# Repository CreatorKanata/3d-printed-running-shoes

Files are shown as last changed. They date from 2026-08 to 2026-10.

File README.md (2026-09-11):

<!-- README.md | Project overview and navigation | Introduce the K-Dash research project. -->

# K-Dash: Fully DIY 3D-Printed Running Shoes Designed for Speed

<p align="center">
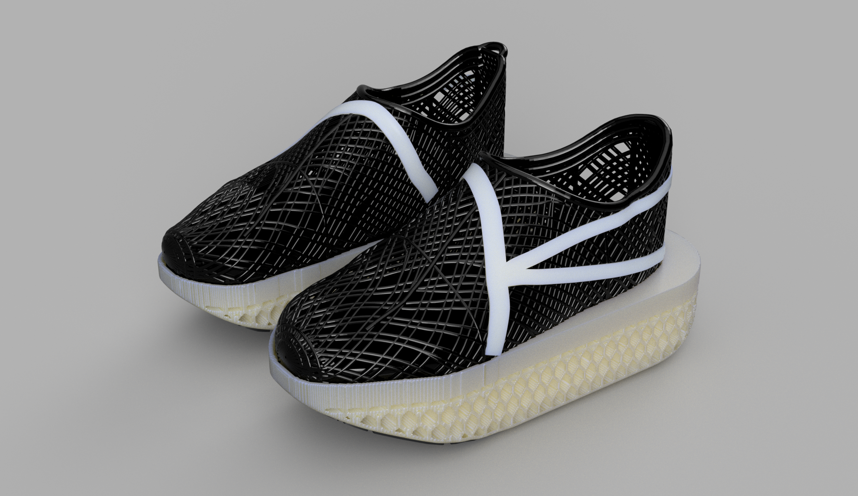
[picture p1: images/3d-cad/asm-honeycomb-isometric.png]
Isometric view of the fully DIY K-Dash 3D-printed running shoes
  
</p>

<p align="center">
  <a href="https://www.youtube.com/watch?v=hppxPRyWNDw">
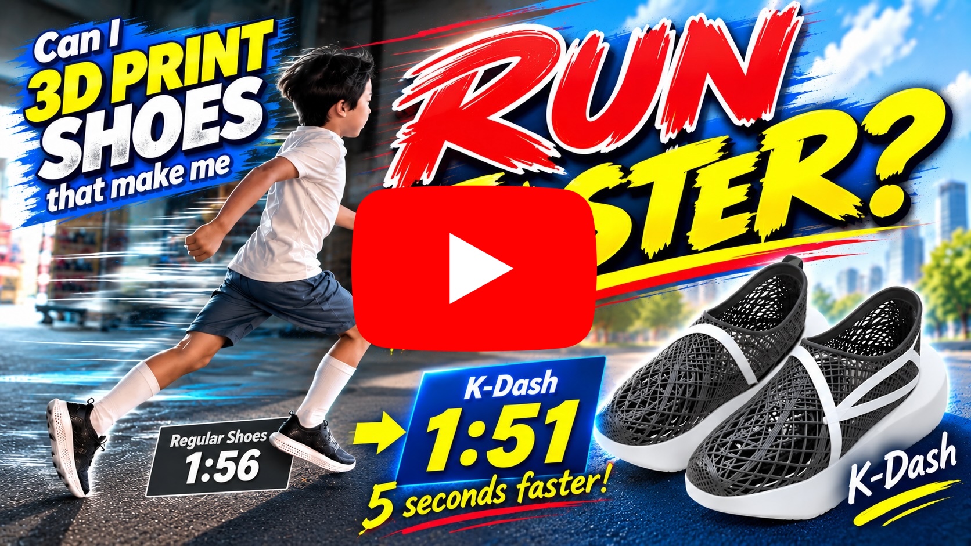
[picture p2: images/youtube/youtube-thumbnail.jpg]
Watch the K-Dash project video on YouTube
    
  </a>
</p>

This summer research project was conceived by Kanata, a third-grade elementary school student. By scanning his own feet and learning about shoe design from his running club coach, he is taking on the challenge of making K-Dash: fully DIY running shoes designed for speed, using AI, 3D CAD, and a 3D printer. His father offers technical suggestions and support with scanning, CAD, material selection, and printing.

## Research Goals

Explore the design features of shoes intended for faster running while making running shoes that fit his own feet.

- Investigate the raised toe, thick sole, and plate features described by the coach.
- Examine commercially available shoes for design ideas.
- Scan his feet in 3D and design closely fitting uppers.
- Find suitable 3D-printing settings through small prototypes and material comparisons.
- Incorporate a polycarbonate plate that can be made at home into the sole.

## Filament Used in the Final Version

- Filament: [Siraya Tech Flex TPU Air Active Foaming 3D Printer Filament](https://www.amazon.co.jp/dp/B0DZCD4Z9M)
- Colors: White and Black
- Nozzle diameter: 0.6 mm

## Research → Design → Build

### 1. Learn from the Coach and Examine Commercial Shoes

<p align="center">
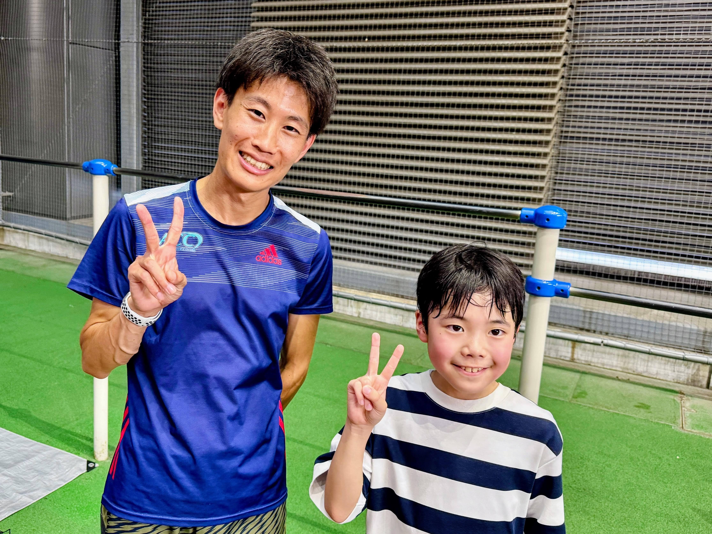
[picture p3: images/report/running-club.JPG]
Running club coach
  
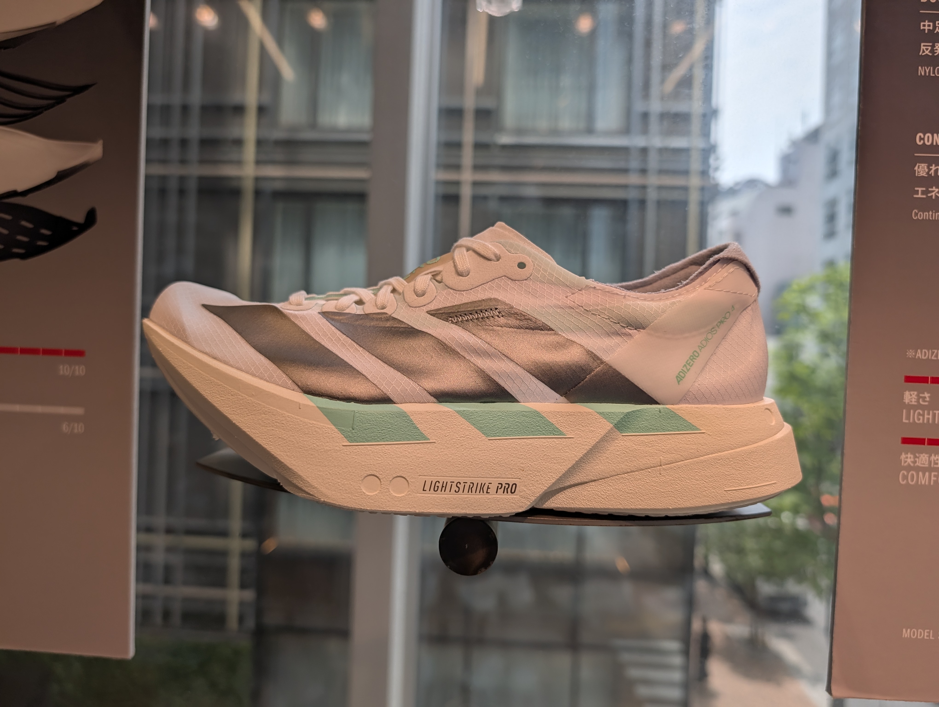
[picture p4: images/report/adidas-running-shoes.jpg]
Running shoes examined at an Adidas store
  
</p>

The coach explained that shoes designed for faster running feature raised toes, thick soles, and plates. We examined actual shoes at an Adidas store in Tokyo and used these features as references for our own shoes.

<p align="center">
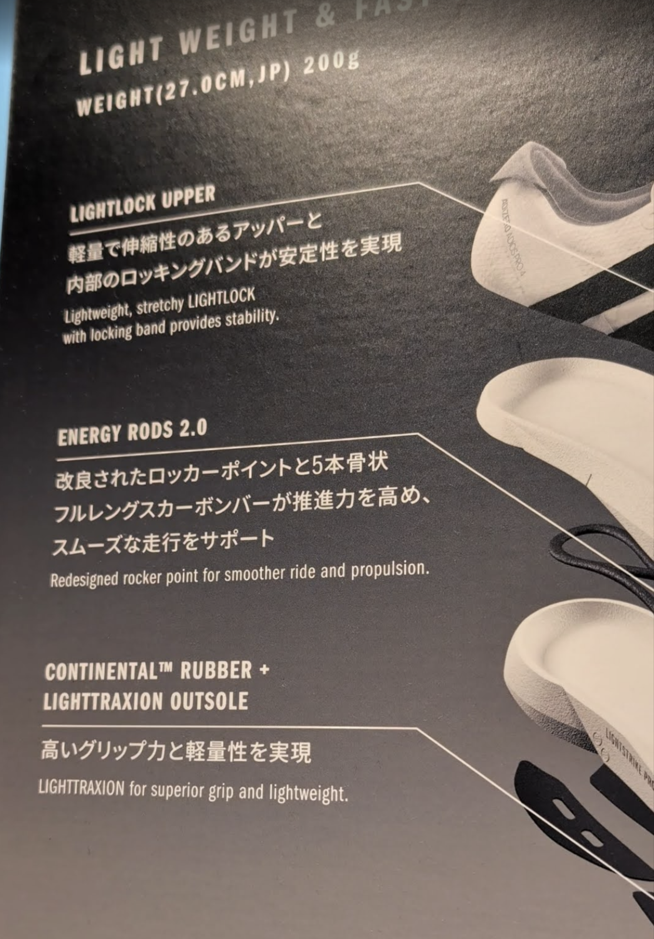
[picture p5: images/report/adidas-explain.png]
Explanation of running shoe construction at the Adidas store
  
</p>

### 2. Turn His Feet into 3D Data

<p align="center">
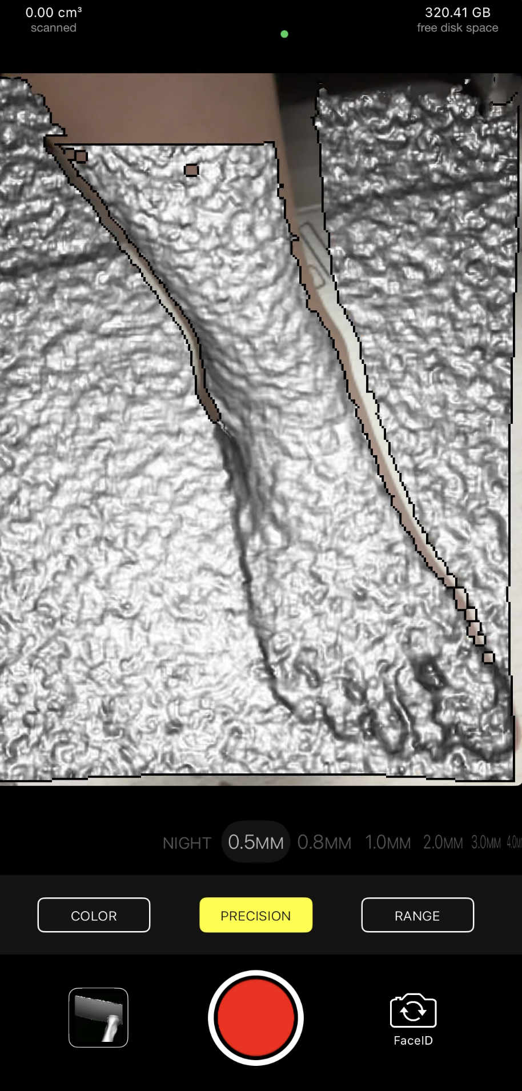
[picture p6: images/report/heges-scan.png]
Scanning a foot in 3D with Heges
  
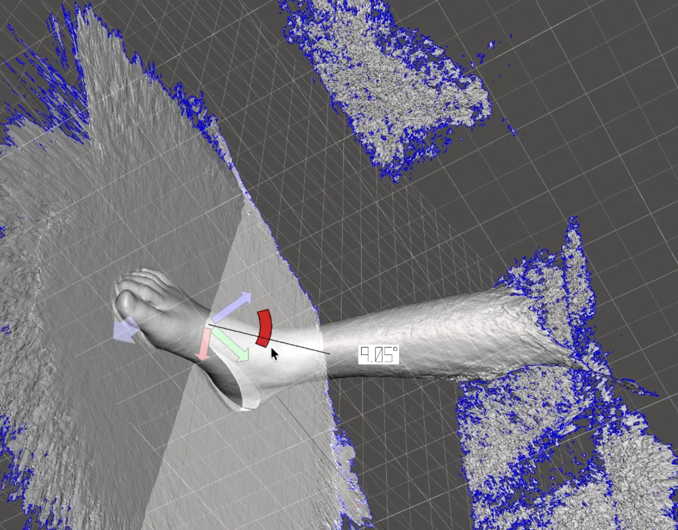
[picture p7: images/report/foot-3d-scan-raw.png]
Raw foot scan containing noise
  
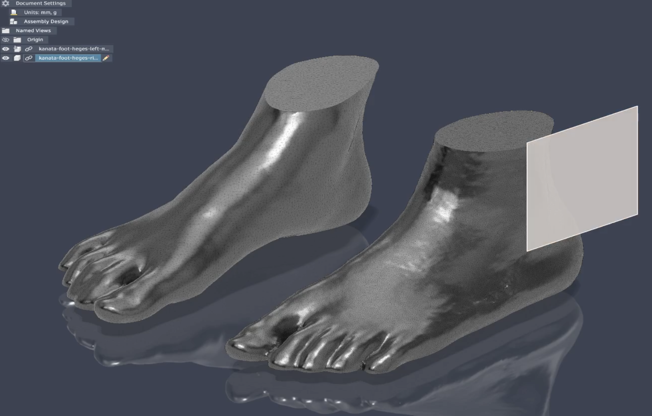
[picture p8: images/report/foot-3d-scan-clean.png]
Foot scan after removing noise
  
</p>

We scanned both feet with Heges and an iPhone's TrueDepth sensor at approximately 0.5 mm accuracy. After removing unwanted areas such as the floor, we prepared the foot models for designing the uppers.

### 3. Design with AI and 3D CAD

<p align="center">
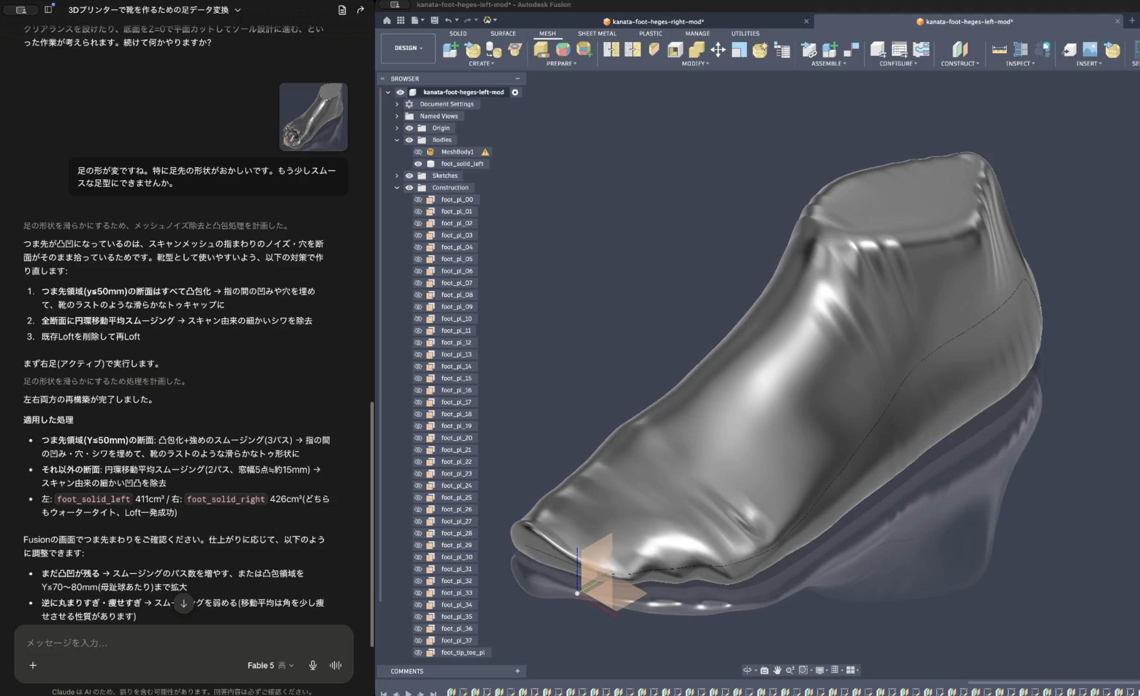
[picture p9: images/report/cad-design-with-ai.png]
Designing with AI and Autodesk Fusion
  
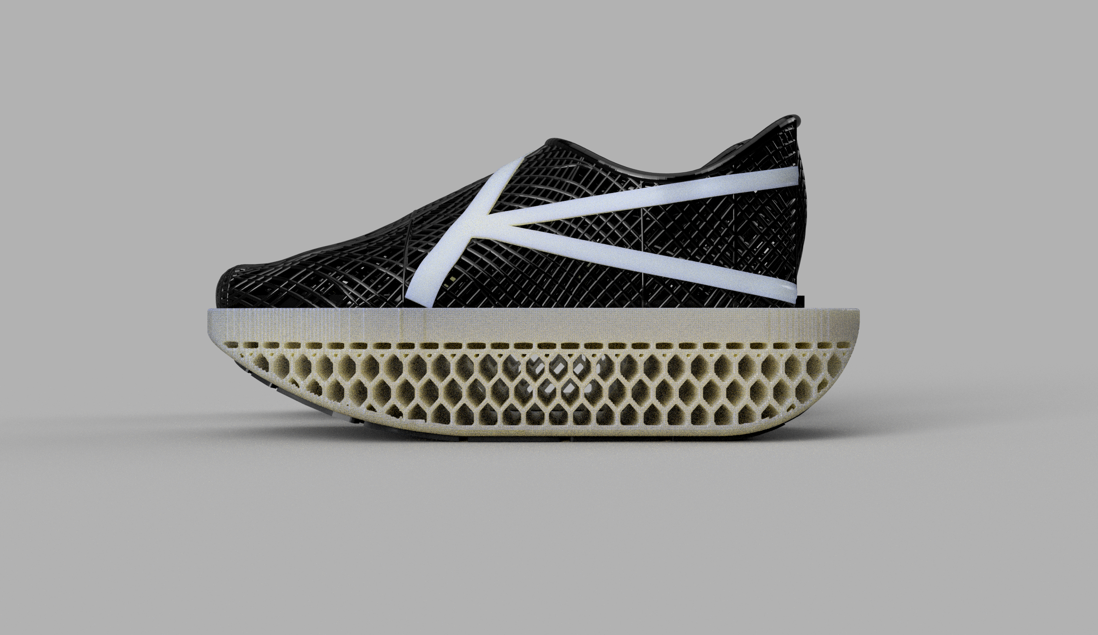
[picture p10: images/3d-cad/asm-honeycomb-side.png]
Side view of the shoe design with a honeycomb sole
  
</p>

We designed the shoes in Autodesk Fusion. By describing the desired shapes to AI and using its help to operate Fusion through MCP, we explored fitted uppers, a raised toe shape, and a honeycomb structure to reduce weight.

### 4. Iterate with 3D-Printed Prototypes

<p align="center">
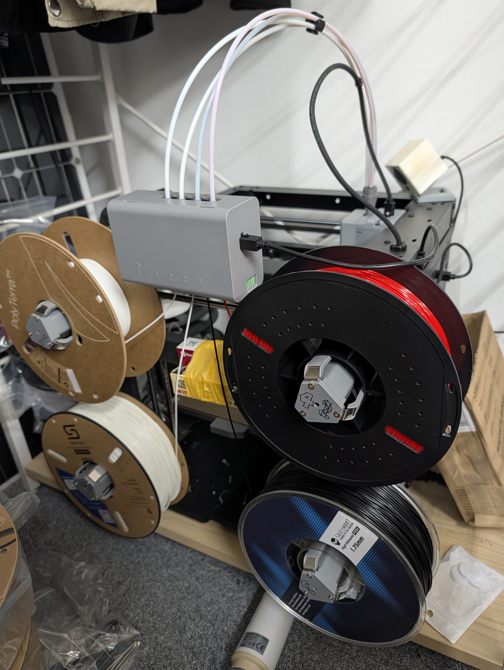
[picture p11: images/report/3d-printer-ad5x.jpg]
FlashForge AD5X 3D printer used for the project
  
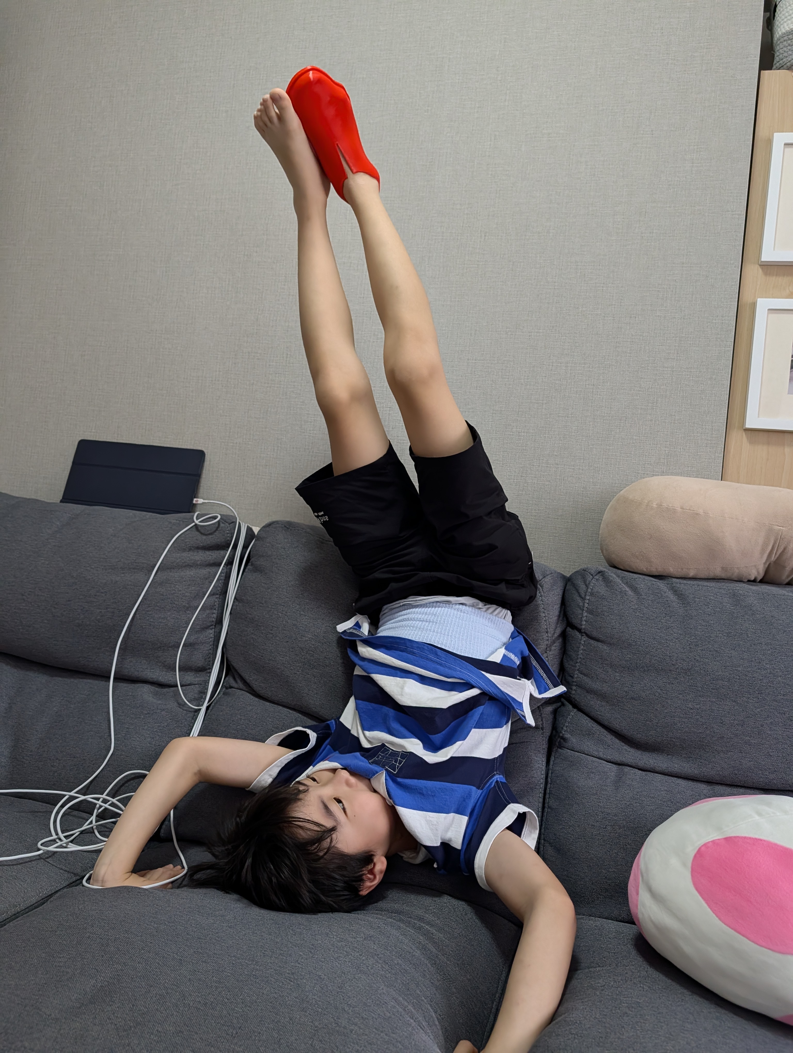
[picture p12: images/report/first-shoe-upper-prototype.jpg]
Trying on the first upper prototype to check the fit
  
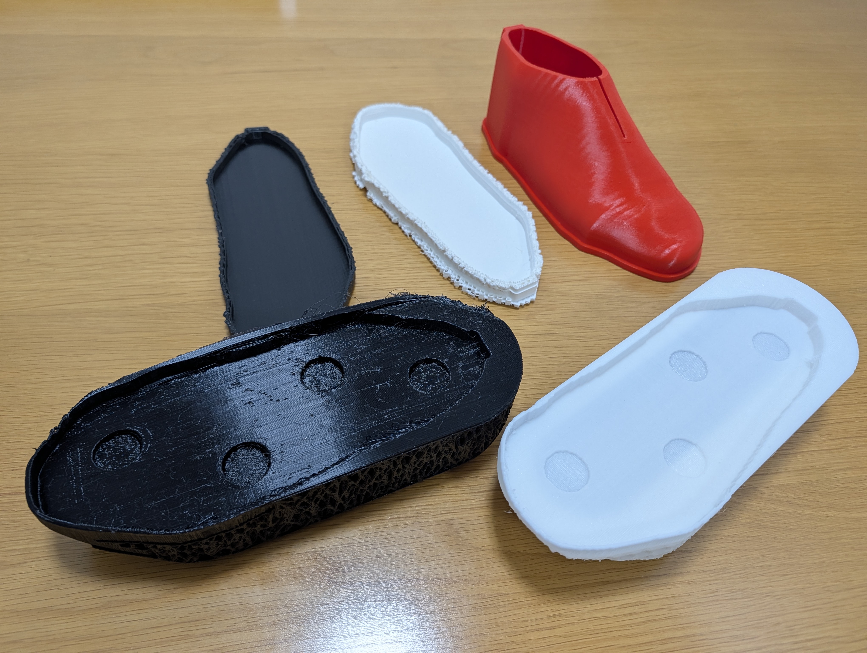
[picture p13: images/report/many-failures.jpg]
Prototypes and failed TPU prints
  
</p>

We first printed only the uppers on a FlashForge AD5X to check the fit. For the final version, we used White and Black Siraya Tech Flex TPU Air with a 0.6 mm nozzle. Soft TPU was challenging to print, so we made many prototypes while adjusting the temperature, nozzle diameter, and filament feeding method.

### 5. Insert a Polycarbonate Plate into the Sole

<p align="center">
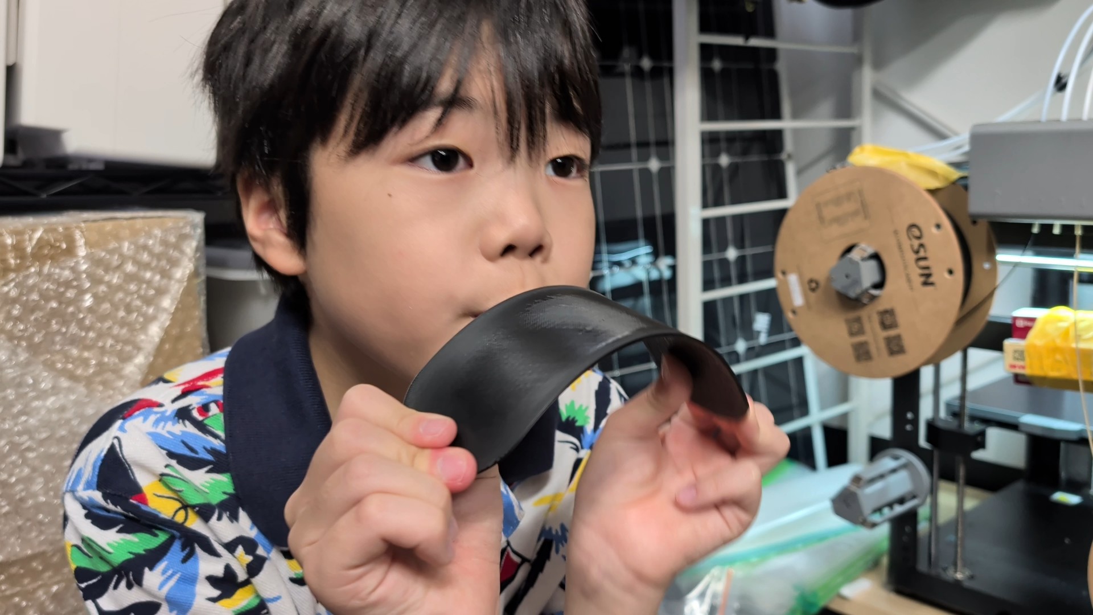
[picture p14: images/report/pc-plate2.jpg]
Polycarbonate plate that springs back after bending without breaking
  
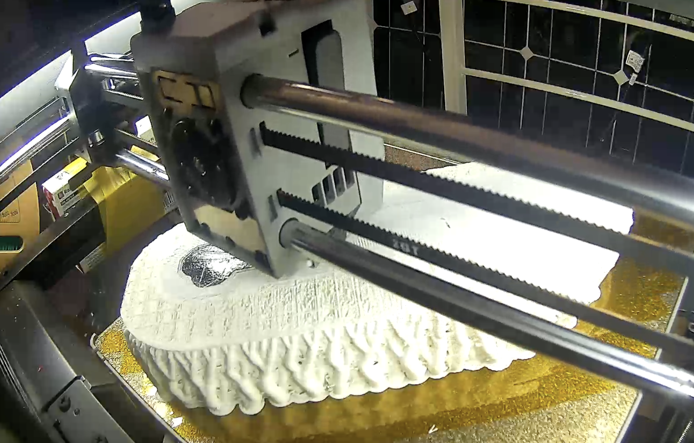
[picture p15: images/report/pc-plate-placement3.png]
Print with a polycarbonate plate embedded in the sole
  
</p>

Because carbon plates are difficult to fabricate at home, we used polycarbonate plates that could be made with a 3D printer. We paused the sole print, placed the plate inside, and resumed printing to embed it in the TPU.

## Folder Structure

| Location | Contents |
| --- | --- |
| [`docs/report/`](docs/report/) | Research report, A3 sketchbook layouts, and sample comments for parents. |
| [`docs/sole-ai/`](docs/sole-ai/) | Technical notes on AI-assisted sole design, lattice structures, and 3D printing. |
| [`images/report/`](images/report/) | Research photos, screenshots, and their descriptions. |
| [`images/3d-cad/`](images/3d-cad/) | Shoe design renderings created with AI and 3D CAD. |
| [`3d-models/`](3d-models/) | Uppers, soles, plates, and slicer profiles for 3D printing. |
| [`sole-ai/`](sole-ai/) | Python tools and tests for generating left and right sole design candidates. |

## Read the Research Report

Descriptions of the research images are collected in [images/report/README.md](images/report/README.md). For the ten-page A3 portrait sketchbook layout, see [docs/report/a3-sketchbook-layout/README.md](docs/report/a3-sketchbook-layout/README.md).

## Sole Design Tools

`sole-ai` is a tool for exploring left and right sole shapes, plate placement, and internal lattice structures. See [sole-ai/README.md](sole-ai/README.md) for usage and design assumptions.

Intermediate candidate data is stored in `sole-ai/outputs/`, and generated files such as PDFs are stored in `output/`. These are not tracked in Git.

## Safety

The 3D models in this repository are intended for research and prototyping. Before running in the shoes, thoroughly check component strength, bonding, and fit. Decide whether to use them for long-distance running or competition only after verifying their safety.

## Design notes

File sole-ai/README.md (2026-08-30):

# Sole AI

`sole-ai` is the starting point for designing left and right 3D-printed racing-shoe soles from scanned geometry, runner intent, and measured test results.

It deliberately separates two jobs:

1. Fusion owns the editable B-Rep master model: sole envelope, upper interface, plate pocket, rocker, and assembly.
2. This project preserves the supplied thick outsole/midsole envelope and creates bounded internal design candidates: a continuous TPU-density field, a curved upper/bottom-midsole split surface, and PC-plate placement. The selected baseline derives the plate outline from the actual left or right sole, leaves the rear cushioning zone plate-free, and follows a moderated version of the outsole rocker. Those candidates are later evaluated by FEA and running tests.

The current manufacturing direction is an FFF-oriented, gently warped, functionally graded walled Gyroid. The earlier stochastic beam network is retained only as rejected research: once constrained for FFF it looked like vertical curtains, and when made visually denser it did not produce a reliable manufacturing mesh. Fusion remains the reference for the locked envelope, curved split, and plate. The density field is a documented load-path heuristic until runner pressure, coupon tests, and FEA data are available, so it does **not** yet predict running performance.

## Geometry to supply

Keep the original Fusion archive (`.f3d`) if it exists. For every side, export the following into `data/raw/<side>/`:

| Priority | Format | Purpose |
| --- | --- | --- |
| Required master | `sole-envelope.step` (AP242, millimetres) | Fusion-editable B-Rep source for all later CAD operations. |
| Required mesh companion | `sole-envelope.stl` (binary, millimetres, watertight) | Mesh validation and implicit growth-lattice generation. |
| Optional | `sole-envelope.3mf` | Preserves slicer/material/print metadata; it is not the CAD master. |
| Strongly recommended | `upper-reference.step` and/or `upper-reference.stl` | Locks the sole to the existing custom upper coordinate frame. |

Export a **closed solid** that includes the entire intended sole envelope—not a 2D outline, an open top surface, or a sliced print plate. The initial Fusion exports use this valid source convention:

```text
X: transverse / width
Y: toe (-) to heel (+)
Z: ground/bottom (-) to upper (+)
units: millimetres
```

The validator infers these axes from the mesh dimensions and records them in each candidate manifest; it never rotates the source CAD. In the Fusion side view used for review, negative Y is screen-right, so the raised plate end is the visible toe. If the upper and sole were exported from different coordinate systems, also place `landmarks.json` next to each side. It must contain at least `heel_center`, `first_met_head`, `fifth_met_head`, and `toe_center` in millimetres. The project will use this later to register the two parts safely.

Do not rely on STL alone for editable Fusion work: STL contains triangles, normally lacks unit metadata, and loses feature history. STEP plus the original `.f3d` is the correct source-of-truth combination. A high-resolution binary STL remains useful for implicit-field work.

## Quick start

This project uses only the Python standard library. Python 3.11 or later is required.
Before physics scoring, replace the `null` runner fields in `configs/baseline.json` with measured values.

```bash
cd sole-ai
python3 -m sole_ai.cli validate --side left
python3 -m sole_ai.cli generate --side left --count 12 --seed 42
python3 -m sole_ai.cli generate-variable-lattice --side left
python3 -m sole_ai.cli generate-organic-lattice --side left
python3 -m sole_ai.cli generate-envelope-lattice --side left
python3 -m unittest discover -s tests -v
```

Copy the generated `outputs/<side>/candidate-*.json` values into the named parameters of the Fusion master model. They are design intents, not a manufacturing model. Do not print a candidate until it has passed the future geometry, FEA, and physical-test gates.

`generate-variable-lattice` writes closed upper/lower STLs and a constraint manifest under `outputs/<side>/lattice/cellular-foam-v2/`. It also writes `*-flashstudio.stl` copies rotated diagonally and moved to Z=0 inside the AD5X 220×220 mm plate. Add `--preview` for Fusion visual-review meshes. Both the manufacturing pair and current high-detail preview use a 1 mm scalar grid.

To create the first actual B-Rep bodies, run the Fusion script in [fusion_addin/README.md](fusion_addin/README.md) after opening the matching STEP. It exports separate Upper Midsole, Bottom Midsole, and PC Plate STEP/3MF files.

When Fusion is unavailable, this project can still create watertight baseline STL bodies that preserve the supplied thick outer shape. This output has no PC-plate pocket or lattice, so use it for visual, fit, and split-line review—not for a final assembled shoe.

```bash
python3 -m sole_ai.cli generate-mesh \
  --candidate outputs/left/candidate-left-0042-001.json
```

## FFF TPU lattice core

The manufacturing-process review and acceptance criteria are recorded in
[../docs/sole-ai/FFF_TPU_LATTICE_RESEARCH.md](../docs/sole-ai/FFF_TPU_LATTICE_RESEARCH.md). The blue
Nagase reference is a photopolymer aesthetic target; AD5X output must additionally
satisfy FFF build-direction, overhang, and bridge constraints.

The selected AD5X topology is a continuous Gyroid surface with gentle long-wave phase warping. Pressure and FEA data will vary exact wall thickness smoothly, while a minimum wall is preserved everywhere. This sacrifices exact visual reproduction of the blue Nagase photopolymer reference in exchange for the FFF TPU printability and fatigue evidence documented in the research note.

An explicitly requested organic alternative is also available through
`generate-organic-lattice`. It grows irregular curved branches independently
inside each scanned left/right envelope, blends their junctions as one implicit
field, and rejects any non-watertight output. Its requested minimum branch
diameter is 1.2 mm; current branch shafts are designed between 1.6 and 1.8 mm.
The dense V2 uses a 5.0 mm nominal cell scale, 4.0--6.0 mm graded node spacing,
and three or four parent branches per node. Only the multi-branch nodes become
locally wider as the branches merge. It remains a test candidate until coupon
and cyclic-compression validation are complete.

When the designer supplies `sole-lattice-left/right.step` plus matching closed
STLs, `generate-envelope-lattice` fills each dedicated volume directly. It does
not split the volume at a plate plane. Every disjoint vertical solid interval is
sampled separately, so a designed gap between stacked or stepped source parts
remains empty. V10 uses independently sampled attraction points in every build
layer. An orthotropic k-nearest graph grows toward them, then adds anastomosis
links so branches split and merge instead of forming a regular vertical grid.
Curved branches are fused by a smooth implicit union. This research basis and
the implementation choices are recorded in
[`../docs/sole-ai/BIOLOGICAL_LATTICE_RESEARCH.md`](../docs/sole-ai/BIOLOGICAL_LATTICE_RESEARCH.md).

The 1.2 mm conformal top/bottom anchors eliminate free branch tips at the two
assembly interfaces. No side anchor or side shell is added. Every complete
branch cross-section stays inward from the lateral boundary, so a free branch
cannot terminate by being clipped on a left/right side face. Free branch shafts
vary continuously across the requested 1.5--2.0 mm range. The V10 branch/node
plan-view density target is 50% of V8: node targets are multiplied by 0.50,
while spacings and coverage radii are multiplied by `1/sqrt(0.50)`. This changes
network count density rather than promising a proportional material reduction.
Intervals 6 mm thick or thinner remain solid to preserve their designed edge
shape. The production-grid single-parent-node ratio is 8.15% left and 8.83%
right, so V10 caps it at 9% while retaining the average-link,
no-dead-end, side-clearance, and 45-degree build-angle gates.

- Forefoot propulsion zone: thickest TPMS walls near toe-off.
- Plate load path: locally reinforced around the approved low rocker-following PC plate.
- Midfoot and heel rim: moderate wall reinforcement.
- Central heel and lightly loaded transitions: thinner walls without disconnected gaps.

The requested minimum feature is 1.5 mm. The first 0.6 mm-nozzle coupon range is deliberately more conservative: 2.4--3.2 mm TPMS wall thickness. A 3 mm ground skin, 2 mm upper bonding skin, and 2 mm solid TPU support on both faces and around the edge of the PC-plate pocket remain mandatory. No full-sole STL is currently labelled print-ready; see the research note for the failed gates and coupon plan.

## Thick-sole constraint

The supplied shoes use a thick, smooth rocker midsole. In V1, `sole-envelope.step` remains the external boundary: the AI must not reduce stack height or change the approved rocker. It may open the side volume to reveal the growth lattice while preserving solid top, ground, and plate interfaces. The plate is centred on a curved split surface derived from the measured outsole underside, so both printed TPU parts capture it.

## Project layout

```text
data/raw/                 input CAD and mesh files, never generated files
configs/                  runner and manufacturing constraints
outputs/                  reproducible candidate manifests
../docs/sole-ai/          research and manufacturing notes
sole_ai/                  standard-library Python package
tests/                    regression tests
```

## Development sequence

1. Add left and right STEP/STL envelope pairs and validate their bounds.
2. Build the Fusion master model by retaining the supplied outer envelope and using the internal named parameters emitted by this project.
3. Replace the design-manifest export with a geometry adapter for the Fusion API.
4. Calibrate the cell-spacing-and-diameter-to-stiffness relation with printed coupons.
5. Add quasi-static FEA and plantar-pressure data, then replace the current smooth heuristic field with optimized runner-specific weights.

This order keeps the first prototypes inspectable and avoids training an "AI" on unverified assumptions.

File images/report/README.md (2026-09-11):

<!-- images/report/README.md | Research image captions | Explain the process and findings alongside the photos. -->

# Image Descriptions for the Research Project

These descriptions accompany the photos and screenshots in this folder for the research project, “Making 3D-Printed Running Shoes That Fit My Feet.” To explain the process and design choices clearly, arrange the report in this order: **motivation → commercial shoe research → foot scanning and design → reviewing the finished CAD design → printing and prototyping → soles with embedded plates → finished shoe weight and running tests**.

Each “Suggested caption” is intended to fit beside or below its image. Commercial shoe specifications vary by model, so describe what can be seen in the photos.

## 1. Motivation and Commercial Shoe Research

### `running-club.JPG` — Learning About Fast Shoe Designs from the Coach

**Suggested caption:** My running club coach taught me that running shoes have features designed to help people run faster. I used carbon plates, raised toes, and thick soles as ideas for my own shoes.

**Key point:** Before making my shoes, I asked an expert how shoes can make running easier.

### `adidas-store.png` — Examining Shoes at an Adidas Store

**Suggested caption:** I visited an Adidas store in Tokyo to learn about the running shoes my coach recommended. Seeing them in person helped me observe shapes and materials that photos alone could not show.

**Key point:** I gathered design ideas by examining actual commercial shoes.

### `adidas-explain.png` — An In-Store Explanation of Shoe Construction

**Suggested caption:** The store had a display explaining how running shoes are built. I learned that shoes are more than their appearance: soles, plates, and other parts help make running easier.

**Key point:** The store display helped me learn how shoes work inside.

### `adidas-running-shoes.jpg` — Features of Modern Running Shoes

**Suggested caption:** The running shoes in the store had features my coach described, including raised toes, thick soles, and structures containing carbon components.

**Key point:** I could see the features my coach described in actual shoes.

### `competitive-analysis.jpg` — Comparing Shoe Brands

**Suggested caption:** With help from AI, I researched the features of different running shoe brands. I learned that companies use plates and cushioning in different ways.

**Key point:** I compared ideas from several companies to inform my design.

### `competitor-adidas.png` — Competitor Research: adidas

**Suggested caption:** I studied adidas shoe structures containing carbon components. I learned that springy parts are used to help move the foot forward.

**Key point:** I used carbon-based spring-back features as a design reference.

### `competitor-new-balance.png` — Competitor Research: New Balance

**Suggested caption:** I studied an example of New Balance shoes with a wavy carbon plate. I learned that companies also have different ideas about plate shapes.

**Key point:** Even carbon plates can use different shapes to achieve their design goals.

### `competitor-nike.png` — Competitor Research: Nike

**Suggested caption:** I studied Nike shoes that combined carbon components with air cushioning near the front. I learned that plates and cushioning can be used together.

**Key point:** I considered cushioning, as well as spring-back, important for comfortable running.

## 2. Turning My Feet into 3D Data

### `heges-scan.png` — Scanning My Feet with Heges

**Suggested caption:** To make uppers that fit well, I scanned both feet with an app called Heges. Using the iPhone's TrueDepth sensor, I captured their shapes at approximately 0.5 mm accuracy.

**Key point:** I first measured my foot shapes accurately to make shoes fitted to my feet.

### `foot-3d-scan-raw.png` — The Raw Foot Scan

**Suggested caption:** The scan captured the floor and nearby objects as well as my feet. I needed to remove the unwanted parts before using the data to design the shoes.

**Key point:** The raw 3D scan needed cleaning before it could be used.

### `foot-3d-scan-clean.png` — The Foot Scan After Removing Noise

**Suggested caption:** After cutting away the floor and surrounding noise, only the 3D foot data remained. I used it to design uppers matching my feet.

**Key point:** Cleaning the data produced foot models suitable for design.

## 3. Designing with AI and 3D CAD

### `cad-design-with-ai.png` — Designing with AI and Autodesk Fusion

**Suggested caption:** I used Autodesk Fusion, a 3D CAD application, for the design. I described the shapes I wanted to AI tools such as Claude and GPT-5.6 Sol, which helped operate Fusion through MCP.

**Key point:** I used AI as a tool to turn my ideas into 3D shapes.

### `../3d-cad/asm-honeycomb-front.png` — Front View of the Finished Design

**Suggested caption:** This is a front view of the shoes designed with AI and CAD. I checked the combination of mesh-like uppers and soles that support the feet.

**Key point:** 3D CAD lets me check the overall balance of the shoes from different directions before printing.

### `../3d-cad/asm-honeycomb-side.png` — Side View of the Finished Design

**Suggested caption:** The side view shows the thick honeycomb soles and raised toes. I chose a honeycomb structure instead of solid soles to try to reduce weight.

**Key point:** I used CAD to explore shapes for easier running and structures for lower weight.

### `../3d-cad/asm-honeycomb-isometric.png` — Isometric View of the Finished Design

**Suggested caption:** This angled view shows how the mesh-like uppers, white foot-support reinforcements, and honeycomb soles fit together. I told AI what I wanted to make and checked the overall design in CAD.

**Key point:** 3D CAD lets me adjust the design while checking how the parts connect.

## 4. Prototyping and Adjusting the 3D Prints

### `3d-print-slicer.jpg` — Preparing Prints with a Slicer

**Suggested caption:** I used software called a slicer to convert the CAD models into data the 3D printer could use. I checked the layers and printing order before printing.

**Key point:** A CAD model needs preparation before a 3D printer can print it.

### `3d-printer-ad5x.jpg` — The 3D Printer Used

**Suggested caption:** I made the running shoe parts with a FlashForge AD5X 3D printer. Using a printer suitable for home use allowed me to make repeated prototypes.

**Key point:** A 3D printer can turn my design ideas into physical parts.

### `many-failures.jpg` — Adjusting Print Settings Through Many Failures

**Suggested caption:** I made many prototypes, but soft TPU was especially difficult to print. Printing finally became stable after adjusting the temperature, changing the nozzle from 0.4 mm to 0.6 mm, and using a setup without the filament switcher.

**Key point:** I learned to record failures, consider their causes, and change conditions one at a time.

### `first-shoe-upper-printing.jpg` — Printing the First Upper

**Suggested caption:** I first printed only the upper, the top part of the shoe, to check the fit. I tested a smaller part before making the whole shoe.

**Key point:** I started by making and testing one part to reduce failures.

### `first-shoe-upper-prototype.jpg` — Trying On the First Upper

**Suggested caption:** When I tried on the first upper, it fitted my foot well. Using the scanned foot data helped me make a shape suited to my foot.

**Key point:** The upper designed from the scan also fitted well when worn.

### `shoe-upper-printing.png` — Printing the Full Upper Design

**Suggested caption:** I also printed the full upper design. After trying TPU, PEBA, and other materials and repeatedly adjusting failed prints, I found that White and Black Siraya Tech Flex TPU Air, an active foaming filament, worked best with a 0.6 mm nozzle. For this print, I used a nozzle temperature of 260°C for a hardness of 70A.

**Key point:** Materials differ in hardness and comfort, so I compared them to choose the best fit for the project.

### `insert-insole.png` — Adding an Insole

**Suggested caption:** I added insoles to make the shoes more comfortable. I combined the printed uppers with insoles and adjusted them to reduce rubbing against my feet.

**Key point:** I improved comfort with insoles as well as printed parts.

### `shoe-upper-finish.png` — The Finished Upper with an Insole

**Suggested caption:** The uppers still fitted well after adding the insoles. I confirmed that the custom uppers and insoles worked well together.

**Key point:** I kept checking the fit by trying on the shoes through the final stage.

## 5. Embedding Polycarbonate Plates in the Soles

### `pc-plate1.jpg` — Making a Plate Instead of Using Carbon

**Suggested caption:** Carbon plates were difficult to fabricate at home, so I 3D-printed polycarbonate plates instead. This let me make them inexpensively at home without laser cutting.

**Key point:** I adapted the design by choosing a material I could work with at home.

### `pc-plate2.jpg` — Testing Plate Strength and Spring-Back

**Suggested caption:** When I bent the polycarbonate plate, it strongly tried to return to its original shape without breaking. I tested it by bending it to see whether it could substitute for a carbon plate.

**Key point:** I physically bent the part to test its strength and spring-back.

### `pc-plate-placement1.png` — Choosing Where to Pause the Print

**Suggested caption:** To insert the plate during printing, I paused the sole print when it reached the height where the plate would sit.

**Key point:** I planned an extra step during printing to combine different materials.

### `pc-plate-placement2.png` — Placing the Plate

**Suggested caption:** After pausing the print, I placed the polycarbonate plate, already coated with adhesive, inside the sole.

**Key point:** I considered placement and bonding to keep the plate from shifting.

### `pc-plate-placement3.png` — Resuming the Print to Embed the Plate

**Suggested caption:** Resuming the print after placing the plate embedded it inside the TPU sole. The sequence “pause → place the plate → resume” combined different materials into one sole.

**Key point:** A home 3D printer could produce a sole combining different materials.

## 6. Assembling K-Dash and Testing Weight and Running

### `glue-shoes.png` — Bonding the Uppers and Soles

**Suggested caption:** I glued the printed uppers and soles together to assemble a pair of K-Dash shoes. Aligning the separately made parts was another important step in making the shoes.

**Key point:** I combined the designed and printed parts into wearable shoes.

### `k-dash-wearing.jpg` — Wearing the Finished K-Dash on Both Feet

**Suggested caption:** I tried the finished K-Dash on both feet. These custom running shoes combine black uppers made from scans of my feet with white 3D-printed soles.

**Key point:** The parts I designed, printed, and assembled became shoes I could wear on both feet.

### `weight-normal.jpg` — Regular Shoe Weight: 204 g

**Suggested caption:** For comparison, I weighed the regular running shoes and recorded 204 g. I used this as a baseline for considering how heavy or light K-Dash was.

**Key point:** Measuring weight in the same way lets me compare my shoes with commercial shoes.

### `weight-v1.jpg` — K-Dash v1 Weight: 411 g

**Suggested caption:** K-Dash v1, made with PEBA and TPU, weighed 411 g. Since it was heavier than the regular shoes, I aimed to make the next version lighter.

**Key point:** Measuring the weight showed in numbers what needed improvement.

### `weight-v2.jpg` — K-Dash v2 Weight: 268 g

**Suggested caption:** K-Dash v2, made with TPU Air, weighed 268 g. That was 143 g, or about 35%, lighter than v1 at 411 g. It was still heavier than the regular shoes at 204 g, but changing materials greatly reduced the weight.

**Key point:** I learned that changes to materials and design can substantially improve shoe weight.

### `running-test-normal.png` — Timing a 400 m Run in Regular Shoes

**Suggested caption:** I ran 400 m in regular shoes and timed the run to compare it with K-Dash. This became the baseline for running the same distance.

**Key point:** A comparison experiment needs a recorded baseline.

### `running-test0.png` — Checking K-Dash Before Running

**Suggested caption:** I put on K-Dash and checked the fit and sole condition before running. This finished version combined uppers fitted to my feet with lighter soles.

**Key point:** Before running, I checked whether the shoes fitted and appeared safe to use.

### `running-test2.png` — Running in K-Dash

**Suggested caption:** I ran in the finished K-Dash shoes. I checked that the printed uppers and honeycomb soles could function while running.

**Key point:** I went beyond making the shoes and tested them by wearing them and running.

### `running-side-view1.png` — Slow Motion: Sole Movement 1

**Suggested caption:** I filmed my feet from the side in slow motion while running. I observed the shape of the honeycomb soles during the run.

**Key point:** Slow-motion video lets me examine sole movement in detail.

### `running-side-view2.png` — Slow Motion: Sole Movement 2

**Suggested caption:** In another frame of the slow-motion video, I observed K-Dash from the side as my weight pressed on my foot. I used it to check changes in sole height and shape.

**Key point:** I observed how the soles changed at different stages of the running movement.

### `running-side-view3.png` — Slow Motion: Sole Movement 3

**Suggested caption:** In another frame, I observed my foot pushing off the ground. I checked whether the honeycomb sole kept its shape without breaking during the running movement.

**Key point:** Video helps inspect how parts move and whether they remain intact during running.

## Usage Notes

- Start with the “Suggested caption” below each image for readability.
- For scanning, prototyping, and plate tests, use the sequence **initial challenge → design choice or adjustment → finding** to explain the research process.
- Finish by comparing the regular shoes and K-Dash under the same conditions: 400 m times, comfort, and sole condition after running. This makes the results easier to understand.

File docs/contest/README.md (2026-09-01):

<!-- docs/contest/README.md | 科学コンテスト用A3縦2枚の使い方 | 要項に沿って印刷・提出するため -->

# 科学コンテスト 2026 提出用レイアウト

東京銀座ライオンズクラブ・早稲田大学科学コンテスト 2026の要項に合わせた、A3縦2枚のSVGです。

| ページ | 内容 |
| --- | --- |
| `k-dash-science-contest-page-1.svg` | 研究の動機、予想、調査、足の3Dスキャン、設計、試作と材料選び。 |
| `k-dash-science-contest-page-2.svg` | 重さと400m走の比較、走行中の観察、考察、次に調べること。 |

## 提出前の確認

- A3縦（297 mm × 420 mm）で、原寸・カラー印刷する。
- 先頭に研究テーマ、学校名、学年、氏名を記載済み。要項どおりクラス名は入れていない。
- 時間の結果は、400mをそれぞれ1回測った今回の比較である。靴だけの効果とは断定せず、次回は同じコース・条件で複数回測る計画を示している。
- 使用写真はSVGに埋め込んであるため、SVGファイルだけを別のパソコンに渡しても表示される。印刷前に、SVGをブラウザまたはInkscapeで開いて、画像が表示されることを確認する。
- 写真は自分たちで撮影したものとして使用する。外部の写真や図を追加する場合は、出典を追記する。

## 制作のねらい

色鉛筆・マーカー・手書き風の矢印や星を使いながら、見出しと測定値は太く読みやすくしました。独創性は「自分の足の3Dスキャンから靴を作ったこと」、分析力は「重さと400mの測定値、1回の測定だけでは結論にできないという考察」で伝える構成です。

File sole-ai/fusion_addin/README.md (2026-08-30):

# Fusion baseline-geometry generator

`sole_ai_fusion.py` is a Fusion script, not a command-line program. It creates real editable B-Rep components from a selected `sole-envelope.step` body and one Sole AI candidate JSON.

## What it generates

- `BOTTOM_MIDSOLE`: the supplied thick sole envelope below the candidate split surface.
- `UPPER_MIDSOLE`: the same envelope above that split surface.
- `PC_PLATE`: a clearance-pocketed PC plate whose planform is trimmed by a scaled copy of the actual left or right sole. It starts after the heel cushion, has a smooth semicircular rear cap, and follows a moderated version of the measured outsole rocker toward the negative-Y toe.
- `*.step`, `*.3mf`, and `sole-ai-assembly.f3d` under `outputs/<side>/geometry/<candidate-id>/`.

The source sole envelope is copied before it is split; it is hidden after a successful run but not deleted. The visible white exterior stays exactly as supplied. The generator creates an internal clearance pocket in both TPU components for the PC plate.

## Lattice responsibility

Fusion owns the reference CAD: locked sole envelope, approved rocker-following plate, and curved upper/lower split. The 2 mm upper skin, 3 mm ground skin, 2 mm plate supports, and biological open-cell lattice are fused into closed meshes outside Fusion by `python3 -m sole_ai.cli generate-variable-lattice --side <side>`.

Import the `lower/upper-organic-strut-preview.stl` pair only for visual review in Fusion. Use the matching non-preview pair as the high-resolution manufacturing source after slicer and coupon validation. Both pairs come from the same deterministic growth history; only surface sampling resolution differs.

Run `import_variable_lattice_preview.py` from **Utilities → Scripts and Add-Ins** to load that generated pair into the current Fusion design. The importer performs no lattice Boolean or density calculation in Fusion.

## Run it in Fusion

1. Open `data/raw/left/sole-envelope.step` or the matching right-side STEP in Fusion's **Design** workspace.
2. Open **Utilities → Scripts and Add-Ins**, add/run `sole_ai_fusion.py` from this folder.
3. Paste the absolute path to the matching candidate JSON when prompted, for example:

   ```text
   /Users/hide/src/github.com/CreatorKanata/3d-printed-running-shoes/sole-ai/outputs/left/candidate-left-0042-001.json
   ```

4. Select the imported closed sole B-Rep body.
5. Inspect the generated `SOLE_AI_<candidate-id>` component: ensure that the plate pocket remains inside the thick sole and that the outer silhouette has not changed.
6. Use the generated STEP files for edits and the 3MF files only after reviewing the clearance and print orientation.

## Fusion MCP execution

Fusion MCP can run the same workflow without modifying the source model that is already open. Import the matching STEP into a new, unsaved document, generate the assembly there, and export the result. This keeps the original scan-lock document untouched.

The low, rocker-following, heel-relieved pair has been generated from candidate `0042-001`:

| Side | Candidate | Generated directory |
| --- | --- | --- |
| Left | `left-0042-001` | `outputs/left/geometry/left-0042-001-low-rocker-smooth-heel/` |
| Right | `right-0042-001` | `outputs/right/geometry/right-0042-001-low-rocker-smooth-heel/` |

Each directory contains separate bottom-midsole, upper-midsole, and PC-plate STEP/3MF files, `sole-ai-assembly.f3d`, and `generation-report.json` with the sampled rocker coordinates. The plate starts 18% forward of the heel, stops at 93% of the heel-to-toe length, and has a 40 mm rounded rear cap. Its deepest centre is 17.5 mm above the global ground minimum—5.72 mm lower than the previous version—and it follows 45% of the measured outsole rocker amplitude. Its planform is the actual side-specific sole B-Rep scaled to 74% in width and 92% in length so the FFF lattice remains visible and printable beside the 2 mm cradle. The F3D is a generated artifact; the unsaved Fusion document can be discarded after confirming the exports.

## Current boundary

This is a genuine B-Rep reference assembly plus a script-grown, variable-density branch network. The PC plate has a side-specific inset footprint, heel-cushion relief, and a measured rocker-following profile. Growth is currently guided by smooth biomechanical zones rather than measured plantar pressure, so coupon tests, FEA, and running validation are still required before the sole is treated as race-ready.

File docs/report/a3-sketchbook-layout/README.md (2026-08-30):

# A3縦スケッチブック・レイアウト

小学3年生のかなたくんの夏休みの自由研究を、A3縦（297 × 420 mm）のスケッチブック10ページにまとめるための台紙データです。各SVGは実寸のA3で作られており、黄色の枠が写真を貼る場所、青い枠が手書きで仕上げる場所です。

## 使い方

1. 各SVGをA3縦で、**拡大・縮小なし（100%）**で印刷します。
2. 写真の枠に、ファイル名どおりのL判プリントを貼ります。縦向きの枠は89 × 127 mm、横向きの枠は127 × 89 mmです。
3. 鉛筆や色ペンで、青い点線枠の質問・図・結果をかなたくん自身の言葉で書きます。

`images/report` と `images/3d-cad` のPNG/JPG画像28枚は、すべて一度ずつ配置しました。`images/report/report-front-page.pdf` は写真ファイルではないため、L判写真枠には含めていません。表紙の文字の参考として使えます。

| ページ | 内容 | 写真枚数 |
| --- | --- | ---: |
| 1 | 研究のきっかけ | 2 |
| 2 | 市販シューズの調査 | 3 |
| 3 | 会社ごとの工夫の比較 | 3 |
| 4 | 足の3Dスキャン | 3 |
| 5 | AIとCADでの設計 | 4 |
| 6 | 3Dプリントの失敗と調整 | 3 |
| 7 | アッパーの試作とフィット確認 | 3 |
| 8 | インソールとプレートの準備 | 3 |
| 9 | プレート入りソール | 4 |
| 10 | 結果・感想・次の改良 | 0 |

この順番なら、**なぜ作るのか → 調べる → 自分の足を測る → 設計する → 試す → 工夫する → 分かったこと**という自由研究の流れになります。

## 保護者向け：コメントを一緒に考えるとき

[COMMENT_EXAMPLES.md](COMMENT_EXAMPLES.md) に、各ページでかなたくんが書ける一人称の例文と、お父さんが使える短い声かけをまとめています。例文をそのまま写すのではなく、本人が話した内容に合わせて選んだり直したりしてください。

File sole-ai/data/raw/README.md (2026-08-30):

# Sole AI input geometry

Place source files here without replacing the existing `3d-models/` prototypes.

```text
left/
  sole-envelope.step
  sole-envelope.stl
  upper-reference.step        # recommended
  upper-reference.stl         # recommended
  landmarks.json              # only when coordinate frames differ
right/
  sole-envelope.step
  sole-envelope.stl
  upper-reference.step        # recommended
  upper-reference.stl         # recommended
  landmarks.json              # only when coordinate frames differ
```

`sole-envelope.stl` must be a watertight binary STL in millimetres. The validation command reads it without modifying the input. The STEP file remains the Fusion source of truth.

For the designer-owned full-volume organic lattice workflow, place these
watertight millimetre solids alongside the older envelope convention:

```text
left/sole-lattice-left.step
left/sole-lattice-left.stl
right/sole-lattice-right.step
right/sole-lattice-right.stl
```

Run `python3 -m sole_ai.cli generate-envelope-lattice --side left`. The STEP
remains the editable CAD master; the matching binary STL is sampled without
modifying either source file. Separated vertical solids are preserved as
separate intervals rather than being joined across their designed air gap.

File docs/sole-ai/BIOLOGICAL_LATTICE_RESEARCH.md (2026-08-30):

# Biological lattice research: where, what, and why

This note records the research basis and safety constraints for the biological
sole lattice generated by `generate-envelope-lattice`. It is a geometry design
candidate, not proof that the sole can safely carry a runner. Coupon fatigue,
compression, printability, and shoe-level validation remain mandatory.

## Primary research used

- Martínez, Song, Dumas, and Lefebvre, *Orthotropic k-nearest Foams for
  Additive Manufacturing* (ACM TOG, 2017),
  <https://doi.org/10.1145/3072959.3073638>. The paper supports stochastic,
  non-periodic k-nearest foam synthesis with freely oriented anisotropy and
  smooth spatial grading.
- Martínez, Dumas, and Lefebvre, *Procedural Voronoi Foams for Additive
  Manufacturing* (ACM TOG, 2016),
  <https://doi.org/10.1145/2897824.2925922>. It motivates aperiodic open-cell
  foam, local density control, and implicit evaluation for fabrication.
- Runions, Lane, and Prusinkiewicz, *Modeling Trees with a Space Colonization
  Algorithm* (Eurographics, 2007),
  <https://doi.org/10.2312/NPH/NPH07/063-070>. It provides the attraction-point
  growth model used to make branches divide and converge organically.
- Tero et al., *Rules for biologically inspired adaptive network design*
  (Science, 2010), <https://doi.org/10.1126/science.1177894>. It motivates
  anastomosis: redundant loop connections that balance path cost and fault
  tolerance rather than leaving a fragile tree.
- Kumar et al., *Inverse-designed spinodoid metamaterials* (npj Computational
  Materials, 2020), <https://doi.org/10.1038/s41524-020-0341-6>. It supports
  non-periodic, smoothly graded, directionally biased, bone-like cellular
  materials without a repeated unit cell.
- Wu, Aage, Westermann, and Sigmund, *Infill Optimization for Additive
  Manufacturing—Approaching Bone-Like Porous Structures* (IEEE TVCG, 2018),
  <https://doi.org/10.1109/TVCG.2017.2655523>. It supports locally constrained
  porous infill as a route to sparse but stable bone-like structures.

## Implemented adaptation

The current generator is a conservative hybrid rather than a verbatim copy of
one paper:

1. Each left/right source STL is rasterized independently. Separated vertical
   solids remain separate; neither foot is mirrored from the other.
2. Stochastic attraction points are sampled independently per build layer.
   V10 targets 50% of the V8 plan-view node density. Node targets are multiplied
   by 0.50, while spacing and coverage radii scale by `1/sqrt(0.50)` so coverage
   repair does not silently restore the old density.
3. Each attraction point connects to two or three valid k-nearest parents in
   the preceding layer. A parent without a child receives a local rescue
   attractor, so no internal free tip is accepted.
4. Multiple parents may reach one attraction and one parent may feed multiple
   attractions. These merge/split paths provide the anastomosis and irregular
   openings associated with living transport networks.
5. Quadratic curved paths are used when every sampled point remains printable
   and inside the source. A straight chord is the conservative fallback.
6. Radius follows a smooth load field and is clamped to 0.75--1.00 mm, giving
   an exact free-branch diameter range of 1.5--2.0 mm.
7. An implicit smooth union rounds every meeting point. Junctions can become
   locally wider where several legal branches merge; individual free shafts do
   not exceed 2.0 mm.
8. The sparse 2.0 mm branches prevent a second legal parent path near a few
   narrow boundaries. V10 permits at most 9% single-parent nodes; measured
   production-grid values are 8.15% left and 8.83% right. Average parent links
   must still exceed 2.2, and internal dead ends remain forbidden.

## Boundary contract

- Bottom and top are the only anchor surfaces. A 1.2 mm conformal anchor layer
  joins the lattice to the outsole and upper-sole interfaces.
- No lateral shell or lateral anchor is generated.
- Every branch surface preserves a measured 0.25 mm side margin. The recorded
  centreline margin varies with the local 0.75--1.00 mm branch radius; a branch
  whose actual surface enters that margin is rejected before STL export.
- Thin source intervals at or below 6 mm remain solid because a reliable
  branch network cannot be fitted there without damaging the supplied shape.
- The final mesh must be watertight, have no side-clipped branches or internal
  dead ends, and pass coverage and parent-link gates before it is written.

## Remaining evidence gap

The literature justifies the topology family, not this exact TPU shoe. The
load field is still heuristic because measured plantar pressure, TPU material
curves, FEA, and cyclic-compression results are not yet available. The V10
density-50 STL must therefore be treated as a review and coupon candidate, not
print-ready running equipment.

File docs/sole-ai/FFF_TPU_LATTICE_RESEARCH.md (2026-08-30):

# FFF TPU midsole lattice research and manufacturing decision

This note records why the lattice generator must be selected from the print
process first. It prevents a visually attractive DLP or powder-bed lattice from
being copied into a supportless AD5X filament build that cannot manufacture it.

## Executive decision

The blue Nagase ChemteX image supplied with this project remains the **aesthetic
target**, but its free 3D branching topology is not direct evidence of a viable
AD5X manufacturing topology. Nagase's primary material literature confirms that
its related flexible RS family is photocured; it does not independently identify
the exact pictured shoe. This project uses a Flashforge AD5X and material
extrusion (FFF/MEX). Because support trapped inside a closed porous midsole
cannot be removed safely, its internal geometry must be self-supporting and
continuously printable in the selected build orientation.

The leading AD5X candidate is a **gently warped, functionally graded walled
Gyroid (TPMS)**. It has a continuous surface instead of isolated beam joints and
is one of the most credible, well-documented candidates in current FFF TPU
cushioning research. It is not assumed to be optimal until coupon testing.

- lower midsole prints from its 3 mm ground skin toward the plate;
- upper midsole prints inverted, from its 2 mm upper-bonding skin toward the plate;
- the starting cell scale is 7.5 mm;
- the wall range is 2.4--3.2 mm for 0.6 mm-nozzle coupons;
- pressure/FEA data changes wall thickness smoothly, never by deleting regions;
- long-wave phase warping reduces visual repetition without generating arbitrary
  unsupported beams;
- exact wall thickness must be restored after warping and measured on the final mesh;
- the slicer must not generate support inside closed, post-processing-inaccessible
  lattice spaces.

An FFF-constrained stochastic beam network was also prototyped and rejected. It
either looked like vertical curtains when every branch was printable, or became
non-manifold when enough curved branches were added to imitate the reference.
It is retained as research code, not an approved manufacturing source.

The selected TPMS will not exactly reproduce a resin or powder-bed Voronoi
lattice. If exact reproduction of the blue reference becomes the priority, the
print process must change to DLP/DLS elastic resin or MJF/SLS TPU.

## Why the reference cannot be copied directly to AD5X

The exact process used for the pictured shoe has not been independently
identified from a primary source. What Nagase's primary documentation does
establish is that its related flexible RS materials are intended for SLA, DLP,
LCD, and inkjet systems, with high-resolution curing and more than 200%
elongation for the flexible RS family. The image is therefore an aesthetic
reference, not evidence that the same unconstrained network is printable in TPU
filament by FFF.

Carbon footwear lattices are produced by Digital Light Synthesis. Carbon's DfAM
guidance separately calls out gradual geometry, consistent wall thickness,
self-support, cleanability, and lattice-specific parameters. That is a complete
process/material/design system, not just an STL pattern.

OECHSLER's lattice library is another important reference, but the Materialise
case study says its production workflow sends the parts to HP Multi Jet Fusion.
The surrounding powder supports arbitrary branches during fabrication. Magics
then checks millions of surfaces and hundreds of thousands of struts before
nesting. Powder-bed success does not demonstrate supportless FFF success.

## Process comparison

| Process | Material support during build | Appropriate lattice freedom | Relevance here |
| --- | --- | --- | --- |
| DLP/DLS/SLA elastomer | Resin process with process-specific supports and cleaning | Fine freeform branches after DfAM validation | Matches the reference aesthetic, not the AD5X process |
| MJF/SLS TPU | Unsintered powder supports the whole part | Voronoi, Delaunay, and arbitrary 3D networks | Strong outsourcing option |
| FFF/MEX TPU | Only the previous layers support new extrusion | Self-supporting TPMS or build-direction-constrained struts | Required for AD5X |

## Evidence for FFF/MEX TPU

Research on supportless flexible TPU lattices identifies overhang angle and
bridging distance as the two critical geometric constraints. A 45 degree limit
is a safe starting approximation, but the bridge limit is material, temperature,
speed, and cooling dependent. A recent FFF review recommends 45--60 degree
overhang compliance and bridges shorter than 5 mm as an initial design region.

TPU honeycomb and gyroid specimens have been printed support-free when their
open areas are small enough and the process has sufficient bridging capability.
TPU gyroids are especially well represented in footwear/cushion research because
they provide continuous load paths, can be graded smoothly, and avoid isolated
beam joints. Functionally graded TPU gyroid testing also found that smooth wall-
thickness transitions can outperform abrupt density transitions in fatigue.

These results do **not** justify sending a full shoe directly to the printer.
They justify generating coupons, mapping the printable window, measuring their
stress--strain response, and only then selecting the sole field parameters.

## AD5X-specific constraints

Flashforge specifies a 220 x 220 x 220 mm build volume, 0.1--0.4 mm layers, and
0.4 mm standard plus 0.6/0.8 mm optional nozzles. TPU 95A is supported for
single-colour printing. The current Flashforge TPU/PEBA guide recommends 0.4,
0.6, or 0.8 mm nozzles for TPU 95A on AD5X, thorough drying, a dedicated clean
nozzle, and reduced feed resistance.

The same guide warns that TPU support removal is difficult and may deform the
part. It recommends PLA when support is unavoidable, while also listing TPU 95A
as incompatible with IFS. A sealed internal midsole must therefore not depend on
disposable support material.

## Geometry acceptance criteria

The next preview is not accepted until it meets all of these checks:

1. **Build direction:** lower `+Z`; upper inverted so its manufacturing direction
   is engineering `-Z`.
2. **Self-support:** slicer overhang and bridge analysis must use the actual
   upper/lower manufacturing orientations; no generated support may remain in
   a closed internal space from which it cannot be removed.
3. **No floating paths:** layer preview must contain no islands disconnected
   from the preceding material.
4. **Wall thickness:** 2.4 mm nominal floor for the first 0.6 mm-nozzle coupon;
   the finished mesh must measure at least 1.5 mm everywhere.
5. **Cell scale:** 6--9 mm initial Gyroid cells with smooth spatial grading.
6. **Interfaces:** upper bonding skin 2 mm, ground skin 3 mm, plate support 2 mm
   on each face, all fused into closed two-manifold bodies.
7. **Visible sidewall:** the plate cradle remains at least 6 mm inboard of the
   visible side lattice; no long external horizontal support band.
8. **Mesh tolerance:** at most one third of the minimum feature size; the final
   2.4 mm minimum-wall model therefore uses 0.8 mm or finer surface tolerance.
9. **Slicer gate:** no support generated in closed, post-processing-inaccessible
   lattice spaces, no floating paths, build bounds valid, and an explicit
   print-time/material estimate.
10. **Physical gate:** print three coupons before the sole, then inspect bridges,
    strand fusion, dimensional error, 40% compression, recovery, and heat build-up.

## Generation methods surveyed

### Repeated beam cells

BCC, FCC, octet, diamond, and auxetic cells are easy to parameterize and simulate.
They can be supportless when oriented deliberately, but an unwarped array looks
regular and artificial. They are useful as calibrated coupon baselines.

### TPMS surfaces

Gyroid, Diamond, and related TPMS structures are implicit continuous surfaces.
They avoid weak beam-to-node contacts and are easy to grade by wall thickness.
For AD5X, a field-warped gyroid is the leading coupon candidate after rejection
of the stochastic strut concept. Exact thickness must be restored after warping
or remapping; nTop documents normalization and exact-thickness workflows for
this purpose.

### Voronoi/Delaunay lattices

Changing point density gives attractive non-periodic geometry, and nTop documents
field-driven volume-mesh-to-lattice shoe workflows. However, unconstrained 3D
edges include horizontal and downward-facing members. Such examples are suitable
for powder-bed or resin processes unless an FFF overhang constraint is added.

### Topology-optimized and field-driven lattices

Pressure and FEA fields should drive cell scale and member diameter. nTop's shoe
workflow imports a pressure scalar point map, remeshes the volume using a smooth
edge-length field, then converts the volume mesh to lattice. For this project the
same field concept is retained, but an FFF build-direction filter is mandatory.

## Coupon programme before a wearable sole

Generate 60 x 60 x 30 mm walled-Gyroid coupons before another full sole:

| Coupon | Cell scale | Wall thickness | Purpose |
| --- | ---: | ---: | --- |
| Soft | 9 mm | 2.4 mm | Heel cushioning baseline |
| Medium | 7.5 mm | 2.7 mm | General midsole baseline |
| Firm | 6 mm | 3.0 mm | Forefoot/plate load-path baseline |

Print using a dedicated 0.6 mm nozzle and dry filament. Fix and record the TPU
brand, hardness, drying cycle, layer height, line width, temperature, speed,
cooling, retraction, and build orientation across all coupons. Record actual
mass, dimensions, inaccessible-support count, failed spans, compression force
at 10/20/30/40%, permanent set after rest, and surface temperature during
repeated compression. These measurements replace guessed density-to-stiffness
values in the optimizer.

## Required production workflow

1. Lock the machine, material hardness, nozzle, layer height, cooling, and build
   orientation before selecting geometry.
2. Print the three Gyroid coupons and an overhang/bridge coupon on the AD5X.
3. Measure as-printed mass, wall error, pore closure, stiffness, recovery, and
   temperature rise; do not calibrate FEA from datasheet TPU alone.
4. Fit a response surface from cell scale and wall thickness to compression behaviour.
5. Import plantar pressure and FEA results as a smooth scalar field.
6. Generate a normalized, exact-thickness implicit Gyroid; clip it to each sole
   half and unite it with the 3/2/2 mm solid interfaces.
7. Repair and validate the final mesh with an industrial lattice/mesh tool or a
   proven equivalent. Every edge must have exactly two incident faces.
8. Slice the actual upper and lower orientations. Reject support generated in
   inaccessible internal spaces, floating paths, excessive bridges, closed
   drainage volumes, or bed overflow.
9. Print a heel/forefoot section before committing to the complete sole.
10. Run quasi-static compression and cyclic testing before any running test.

## Current project status

- Terra image review rejected both experimental beam-network previews.
- The FFF-constrained version met its 45 degree branch-angle rule and nominal
  diameter rule but still looked like vertical curtains rather than the reference.
- The first graded-Gyroid implementation is research code only. Its raw surface
  intersects the sampled source envelope with a small number of non-manifold
  edges, and the attempted local voxel repair has not yet passed the project's
  strict two-faces-per-edge test.
- Therefore no generated STL is labelled print-ready, and Fusion/Flash Studio
  should not receive a replacement final model yet.

## Sources

- [Nagase ChemteX visible-light-curing 3D printing material](https://group.nagase.com/nagasechemtex/en/products/catalog/pdf/3dpe.pdf)
- [Carbon Design for DLS](https://learn.carbon3d.com/design)
- [Materialise/OECHSLER lattice production with Magics and HP MJF](https://www.materialise.com/ja/inspiration/articles/oechsler-3d-printed-lattices-magics)
- [Flashforge AD5X specifications](https://www.flashforge.com/products/flashforge-ad5x-3d-printer)
- [Flashforge TPU/PEBA Usage Guide](https://wiki.flashforge.com/resource/pictures/filament/print_defect_and_solution/tpu_usage_guide.pdf)
- [Design of Flexible TPU-Based Lattice Structures for 3D Printing](https://doi.org/10.3390/polym17091133)
- [Mechanical Properties of Flexible TPU-Based 3D Printed Lattice Structures](https://doi.org/10.3390/polym13172782)
- [Functionally graded TPU gyroid structures for cushioning applications](https://doi.org/10.1080/15376494.2025.2530146)
- [Development of Periodic Cell Structures that Can Adjust Young's Modulus](https://doi.org/10.2472/jsms.73.949)
- [nTop: vary density to create a custom shoe sole](https://support.ntop.com/hc/en-us/articles/360043876354-How-to-vary-density-to-create-a-custom-shoe-sole)
- [nTop: measure TPMS wall thickness](https://support.ntop.com/hc/en-us/articles/18669009073555-How-to-measure-TPMS-wall-thickness)
- [Autodesk Fusion volumetric lattice properties](https://help.autodesk.com/view/fusion360/ENU/?contextId=SLD-VOLUMETRIC-LATTICE)

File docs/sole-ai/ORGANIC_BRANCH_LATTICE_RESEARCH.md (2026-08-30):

# Organic branch lattice generation decision

This note records the algorithm selected for the locally generated left and
right sole meshes. The goal is an irregular, biological branch network rather
than a repeated Cartesian unit cell.

## Methods considered

- Voronoi and Delaunay methods produce controllable irregular trabecular
  networks, but unconstrained edges can create unsupported horizontal members.
- Spinodal methods create smooth stochastic and often bicontinuous phases, but
  direct control of individual branch diameter and build angle is indirect.
- Space-colonization growth produces recognizably organic branching skeletons,
  but a tree alone lacks the closed loops required for a durable sole.
- Signed-distance implicit modeling can turn a graph of curved branches into a
  closed surface and blend multi-branch nodes without fragile Boolean seams.

## Selected hybrid

The implementation combines these ideas:

1. Poisson-like irregular roots are sampled independently inside each scanned
   left/right envelope.
2. Nodes grow layer by layer toward the opposite solid interface, borrowing the
   attraction-and-growth idea of space colonization while keeping every member
   within the configured FFF angle.
3. Every new node receives three or four printable parent links, so the result
   contains many short load-sharing loops instead of a sparse tree.
4. Quadratic Bezier sampling bows every branch and removes dominant grid
   directions.
5. A variable-radius signed-distance field represents the branches. A smooth
   minimum fuses their junctions into rounded, bone-like nodes.
6. The field is clipped by the measured sole columns and united with ground,
   upper-bonding, and plate-support interfaces.
7. Marching tetrahedra extracts the surface. Export is rejected unless every
   quantized edge has exactly two incident faces.

## Current manufacturing bounds

- requested minimum branch diameter: 1.2 mm;
- conservative designed branch-shaft diameter: 1.6--1.8 mm;
- implicit shaft expansion: 0 mm; only junctions receive a 0.05 mm blend;
- nominal irregular cell scale: 5.0 mm;
- node spacing: 4.0--6.0 mm, graded continuously by the load heuristic;
- build-layer spacing: 3.2 mm;
- scalar grid: 0.6 mm;
- maximum branch angle from the build direction: 45 degrees;
- lower and upper halves are generated separately around the PC-plate pocket;
- left and right are generated independently and are never mirrored.

The 1.6 mm design floor intentionally exceeds the requested 1.2 mm. The extra
margin covers scalar-grid and FFF process error while the 1.8 mm shaft ceiling
limits excess mass. The denser V2 adds material by increasing branch and loop
count, not by violating that shaft ceiling. Junctions are locally wider because
several branches must merge into one connected node. Geometry checks do not replace
TPU coupon, compression, fatigue, thermal, and slicer-support validation.

## Primary references

- Runions, Lane, and Prusinkiewicz, *Modeling Trees with a Space Colonization
  Algorithm* (2007): https://algorithmicbotany.org/papers/colonization.egwnp2007.html
- Wang et al., *Machine learning unifies flexibility and efficiency of spinodal
  structure generation for stochastic biomaterial design* (2023):
  https://www.nature.com/articles/s41598-023-31677-7
- *An improved trabecular bone model based on Voronoi tessellation* (2023):
  https://doi.org/10.1016/j.jmbbm.2023.106172
- *A method for generating large-scale implicit lattice structures for direct
  manufacturing* (2025): https://doi.org/10.1016/j.jmapro.2025.07.010

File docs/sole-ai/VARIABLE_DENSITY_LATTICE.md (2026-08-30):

# Cosmic-biological variable-density sole lattice

The printable lattice is generated as mesh data rather than thousands of Fusion timeline features. Fusion supplies the immutable scanned envelope and approved rocker-following plate path. The Python pipeline builds a dense non-periodic cellular foam, unites it with required solid TPU interfaces, and writes closed binary STL files.

## Generative model

This is not a repeated Cartesian cell and it is not a TPMS formula. It uses a deterministic stochastic-cell construction:

1. Non-periodic nodes fill each sole half with a nominal 8.8 mm cell scale.
2. The biomechanical field smoothly reduces local spacing where more support is needed.
3. Each node connects to six irregular neighbours, creating many small interlocking cells.
4. Every connection becomes a five-segment quadratic Bezier curve instead of a kinked wire.
5. The load field also changes branch diameter without abrupt zone boundaries.
6. An implicit union rounds every junction and blends the network, skins, and plate support before one closed surface is extracted.

The result is deliberately non-aligned and densely connected. It should resemble stochastic foam, trabecular bone, and the reference blue cellular midsole more than a manufactured grid.

## Load-guided variation

| Region | Relative growth | Intent |
| --- | --- | --- |
| Forefoot around toe-off | Smaller cells and thicker branches | Transfer load and limit excess collapse |
| Approved plate path | Smaller cells fused to solid support | Carry load without isolated plate-to-lattice contacts |
| Midfoot and outer rim | Medium | Torsional and lateral stability |
| Central heel | Larger cells, while retaining a connected minimum density | Preserve cushioning and reduce mass |

This is a design heuristic, not a measured material model. Printed coupons, plantar pressure, FEA, and running tests must calibrate it.

## Manufacturing constraints

- Requested minimum branch diameter: 1.5 mm.
- Nominal generated branch floor: 1.8 mm.
- Implicit fusion overlap: 0.12 mm per side; effective isolated floor is about 2.04 mm.
- Ground-contact solid TPU: 3.0 mm nominal.
- Upper bonding solid TPU: 2.0 mm nominal.
- PC-plate support: 2.0 mm on each face plus a 2.0 mm closed edge support.
- Sidewall: open cellular foam, with no cosmetic solid skin.
- Manufacturing scalar grid: 1.0 mm.
- Fusion visual-review scalar grid: 1.0 mm, matching the manufacturing mesh.

## Outputs

```text
sole-ai/outputs/<side>/lattice/cellular-foam-v2/
├── lower-cellular-foam.stl
├── upper-cellular-foam.stl
├── lower-cellular-foam-flashstudio.stl
├── upper-cellular-foam-flashstudio.stl
├── cellular-foam-manifest.json
├── lower-cellular-foam-preview.stl
├── upper-cellular-foam-preview.stl
└── cellular-foam-preview-manifest.json
```

The engineering-coordinate pair remains aligned with the Fusion envelope and plate. The `flashstudio` copies are rotated diagonally, translated so Z starts at 0, and checked against the AD5X 220×220 mm bed with a 5 mm margin.

Generate both resolutions with:

```bash
python3 -m sole_ai.cli generate-variable-lattice --side right
python3 -m sole_ai.cli generate-variable-lattice --side right --preview
```

## Validation boundary

Every exported component must have exactly two faces sharing every mesh edge. The pipeline rejects open or non-manifold meshes and rejects Flash Studio copies outside the configured bed. This follows the manufacturing lesson in the [Materialise/OECHSLER case study](https://www.materialise.com/ja/inspiration/articles/oechsler-3d-printed-lattices-magics): complex lattice data requires automated failure checks and nesting, not visual confidence alone.

The multi-zone variation and conformal boundary strategy are informed by [Carbon Design Engine](https://www.carbon3d.com/resources/blog/carbon-advanced-lattices), while the non-periodic point-density concept is related to the Voronoi and custom-lattice categories described by [Evort](https://evort.jp/article/lattice-structure). The present cellular algorithm is project-specific and does not claim to reproduce either proprietary tool.

Geometry validity does not prove durability or running performance. Do not run in the prototype until material coupons, plate-clearance inspection, quasi-static compression FEA, and a low-speed physical test have passed.

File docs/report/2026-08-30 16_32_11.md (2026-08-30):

## 人物・役割別の視点

- かなた君:
  - ランニングクラブで走っており、友達に勝ちたいという動機がある。
  - 3Dプリントのランニングシューズを作る動画を見て、自分でも作れるのではないかと考えた。
  - この自由研究を自分で発案し、「自分の足に合うランニングシューズを3Dプリントで作る」ことに挑戦している。
  - 市販シューズの工夫、作り方、自由研究で伝えたい順番を、自分で考えながら進めている。
  - 実際の結果や感想は、明日にならないと分からない可能性があるため、最後のページにまとめる案が出ている。

- ランニングクラブのコーチ:
  - アディダスのシューズを例に、速く走るための靴の工夫について説明した。
  - カーボンプレート、つま先が上がった形状、分厚いソールなどが、走りやすさや足へのダメージ軽減に関係するという内容が示された。

- 父親（技術面のサポート）:
  - かなた君のアイデアを形にするために、3Dスキャン、AIを使ったCAD設計、3Dプリント、材料比較などの技術面を提案・支援した。
  - 市販シューズの工夫を調べる方法や、試作で確かめる進め方を提案した。
  - かなた君が自分の体験や感想を自由研究にまとめられるよう、質問しながら手伝った。

## 重要ポイント

- テーマ1: 自由研究の目的と背景
  - かなた君はランニングクラブで友達に勝ちたいという目的を持っている。
  - 3Dプリントの靴を作る動画を見たことをきっかけに、自分用のランニングシューズを作ろうと考えた。
  - 自由研究の中心テーマは、かなた君が発案した「自分の足にフィットする3Dプリント・ランニングシューズを作る」こと。

- テーマ2: 速く走るためのシューズ設計の参考要素
  - ランニングクラブのコーチから、速く走れる靴には複数の工夫があると聞いた。
  - かなた君は、コーチに聞いた内容を、自分のシューズに取り入れるための参考にした。
  - 主な参考要素:
    - カーボンプレート:
      - バネのように足を押し出す役割がある。
    - つま先が上がった形状:
      - 走りやすさに関係する設計要素として挙げられている。
    - 分厚いソール:
      - 足へのダメージが残りにくい、または衝撃が響きにくい効果があると説明されている。

- テーマ3: 足の3Dスキャンとアッパー部分の設計
  - かなた君は、完全に足にフィットした靴を作るため、まず自分の両足を3Dスキャンした。
  - 父親は、足の形をデータにする方法と、データをCADに使う手順を技術面から提案した。
  - 使用したアプリ:
    - Hegesとみられる3Dスキャンアプリ。
    - 入力内では「ヘゲス」「Heges」と発話されている。
  - 使用した機能:
    - iPhoneのTrueDepthセンサー。
    - 精度は0.5mmと説明されている。
  - 作業手順:
    - 両足をスキャンする。
    - スキャンデータをインポートする。
    - 余分な部分を取り除く。
    - Autodesk Fusionに読み込ませる。
    - 父親の技術面のサポートを受け、Codexに足の形に完全にフィットする靴のアッパー部分のデザインを依頼する。
  - 成果:
    - 最初に赤い靴のモデルができた。フィッティング用。
    - その後、軽量化のために網目状のデザインにした。
    - 網目状のデザインもCodexに作成してもらった。

- テーマ4: ソール部分の設計と軽量化
  - かなた君は、ソールをそのままプリントすると重くなることを考え、内部を肉抜きする方針にした。
  - 父親は、軽量化とクッション性を両立するための構造として、ハニカム構造を提案した。
  - 採用した構造:
    - ハニカム構造。
  - 目的:
    - 軽量化。クッション性向上。
    - ソールとしての使いやすさの改善。
  - かなた君が考えた目的に合わせ、ハニカム構造のデザインもAIに作成してもらった。

- テーマ5: 素材比較とTPU Airの採用
  - かなた君は、複数の素材を試して、ソールに適した素材を比較した。
  - 父親は、材料や印刷条件を変えて試す方法を技術面から提案した。
  - 試した素材:
    - 通常のTPU:
      - 少し硬かった。
    - PEBA:
      - TPUではない、少し柔らかい素材として試した。
      - それでもまだ少し硬かった。
    - TPU Air:
      - TPUより柔らかい発泡型の素材として説明されている。
      - 温度によって柔らかさを変えられる素材とされている。
      - 軽くて柔らかいため、ソール用として最適だと分かった。
  - 追加事項:
    - アッパー部分もTPU Airでプリントしてみた。
    - 最終的に使ったのは、Siraya Tech Flex TPU Air アクティブ発泡3DプリンターフィラメントのWhiteとBlack。
    - TPU Airはヘッドの温度によって柔らかさが変わるフィラメント。今回は70A（260℃）、0.6 mmノズルで実施した。

- テーマ6: 自由研究に入れたい追加要素
  - かなた君は、他社シューズとの比較も自由研究のどこかに載せたいと考えている。
  - 実験結果や走ってみた感想は、明日にならないと分からない可能性がある。
  - 結果や感想は、自由研究の最後のページに置く案が出ている。

- タスク:
  - 担当: かなた君
  - 内容: 実際に作成した3Dプリントシューズの結果や感想を確認し、自由研究の最後のページにまとめる。
  - 期限: 2026年8月31日 10:00
  - 根拠: 「結果とかは明日になってみないとわかんない」「一番最後のページに置いとけばいい」という発言。
  - 状態: 未完了

- タスク:
  - 担当: かなた君（父親が調査方法をサポート）
  - 内容: 他社シューズとの比較を自由研究のどこかに掲載する。
  - 期限: なし
  - 根拠: 「それ以外の会社の比較っていうのも自由研究の中でどこか載せたい」という発言。
  - 状態: 検討中

- 確認事項:
  - かなた君が追加で入れたいアイデアは何か。
  - かなた君自身の体験や感想として、どのようなことを書きたいか。
  - 実際の走行結果や履き心地の評価内容。
  - 他社比較として、どの会社・どのシューズを対象にするか。

- 未確定事項:
  - 3Dプリントシューズを実際に履いて走った結果。
  - 速度向上や友達に勝てたかどうか。
  - 印刷速度や積層ピッチなど、ノズル径以外の詳しい印刷条件。
  - 他社比較の対象ブランドや比較項目。
  - 自由研究全体の最終ページ構成。

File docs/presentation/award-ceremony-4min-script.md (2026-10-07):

<!-- docs/presentation/award-ceremony-4min-script.md | 科学コンテスト表彰式の4分台本 | 本人の読み上げと動画操作を合わせて練習するため。 -->

# 科学コンテスト表彰式の作品紹介・約4分

対象は城東小学校3年・竹井奏太さんの研究「自分の足に合う3Dプリントのランニングシューズ」です。案内の「3 作品の紹介について」は項目番号として扱い、この1作品のきっかけ、研究内容、感想を紹介します。

約2分の元動画を通常の速さで流し、途中で3回止める構成です。読み上げは約870字。動画の再生中も話すため、元動画の音声はミュートにします。本文は短い文を中心にし、難しい漢字や道具の名前はひらがな・カタカナにしました。

## 大人向け・映像の操作表

- 使用動画 `0909 (1)(1).mp4`。元ファイルは約1分59.56秒。
- 「発表時間」は話し始めてからの経過時間。「動画位置」はプレーヤーに表示される元動画の時間。
- 停止位置は元動画の0:20、1:43、1:55。停止時間は順に20秒、40秒、60秒。
- 元動画119.56秒＋停止120秒＝239.56秒、約4分。舞台への移動と拍手は含みません。
- 本人は読み上げに集中し、大人が再生・停止を担当する想定です。

| 発表時間 | 動画位置・操作 | 話すこと |
| --- | --- | --- |
| 0:00〜0:20 | 0:00〜0:20を再生 | あいさつ・作品名 |
| 0:20〜0:40 | 0:20で20秒停止①。黒いタイトル画面 | 調べようと思ったきっかけ |
| 0:40〜2:03 | 0:20〜1:43を再生 | 調査・設計・試作品・材料・板・組み立て |
| 2:03〜2:43 | 1:43で40秒停止②。完成したくつに「Meet K-Dash」と出る画面 | 完成したくつを見せながら、苦労と作り直し |
| 2:43〜2:55 | 1:43〜1:55を再生 | 完成したくつをはく場面から400m走へ |
| 2:55〜3:55 | 1:55で60秒停止③。2つのタイムが出た画面 | 結果・まだ分からないこと・感想 |
| 3:55〜約4:00 | 1:55〜最後まで再生 | お礼・おじぎ |

## 本人が読む台本

引用枠の中だけを読みます。時刻、見出し、映像の指示は読みません。句点でひと息つき、空行のところは少し間を取ります。下の細かい時刻は練習の目安です。

数字の読み方は「四百メートル＝よんひゃくメートル」「一分＝いっぷん」「五十六びょう＝ごじゅうろくびょう」「五十一びょう＝ごじゅういちびょう」です。

### 0:00〜0:20　はじめのあいさつ

動画 0:00〜0:20を再生。走っている映像に合わせる。

> じょうとう小学校3年の、たけいかなたです。
> ぼくは、家のスリーディープリンターで、走るためのくつを作りました。
> 名前は「ケーダッシュ」です。

### 0:20〜0:40　きっかけ

動画 0:20で停止①。黒い背景に「RUN FASTER」と出るタイトル画面。

> ぼくは、ランニングクラブでもっと速く走って、友だちに勝ちたいと思っていました。
> 自分の足に合うくつを作ったら、もっと速く走れるかな、と考えました。

### 0:40〜1:03　くつのしくみを調べた

動画を0:20から再開。コーチとお店のくつの場面。

> まず、コーチに話を聞いて、お店のくつを調べました。
> つま先が上を向いた形、あついくつぞこ、それから、バネのようにしなる板。
> この3つを、ぼくのくつにも取り入れました。

### 1:03〜1:25　自分の足に合う形を作った

動画はそのまま再生。元動画0:43ごろから足のスキャンと設計の場面。

> 次に、スマホで自分の足をうつして、足の形をデータにしました。
> お父さんにやり方を教えてもらい、作りたいくつの形をエーアイに話して、形を作りました。

### 1:25〜1:40　はいてたしかめた

動画はそのまま再生。元動画1:05ごろから赤い試作品、設計、プリントの場面。

> まず、くつの上の部分を作って、はいてみました。
> 足にぴったりでした。
> でも、くつを全部作るのは大へんでした。

### 1:40〜1:50　軽くするくふう

動画はそのまま再生。元動画1:20ごろからプリントを工夫している場面。

> ざいりょうをかえることで、さいしょに作ったくつより、軽くすることもできました。

### 1:50〜2:03　板を入れて、できあがり

動画はそのまま再生。元動画1:30ごろから板を持つ場面、板を入れる場面、組み立てへ。

> くつぞこには、曲げるともどる板を入れました。
> この板もプリンターで作りました。
> 上下をくっつけて、できあがりです。

### 2:03〜2:43　できあがるまでに、大へんだったこと

動画 1:43で停止②。机の上の完成したくつが大きく映り、「Meet K-Dash」と出る場面。走る映像に入る前に止める。実物があれば、この段落で見せてもよい。

> いちばんむずかしかったのは、やわらかいざいりょうで作ることです。
> うまく形にならず、何度もやり直しました。
> ざいりょうや、プリンターの温度をかえてためしました。
> できたものをたしかめて、うまくいかないところは、また作り直しました。
> できたくつで、本当に速く走れるのか、ためしてみました。

### 2:43〜2:55　走ってくらべた

動画を1:43から再開。完成したくつをはく場面から、走って比べる場面へ。

> できたくつをはいて、四百メートルを走りました。
> ふつうのくつと、ケーダッシュで、時間をくらべました。

### 2:55〜3:55　分かったことと、かんそう

動画 1:55で停止③。「Regular Shoes: 01:56」「K-Dash: 01:51」が見える場面。

> ふつうのくつでは、一分五十六びょう。
> ケーダッシュでは、一分五十一びょうでした。
> 今回は、五びょう速く走れました。
>
> 足にぴったりで、前に進みやすい感じがしました。
> でも、くらべたのは、一回ずつです。
> くつのおかげで速くなったかは、まだ分かりません。
> 次は、同じ場所で何回か走って、たしかめたいです。
>
> 自分で考えたくつをはいて走れて、うれしかったです。
> しっぱいしても、作り直すと少しずつよくなることが分かりました。
> もっと軽くて、走りやすいくつを作りたいです。

### 3:55〜4:00　おわりのあいさつ

動画を1:55から最後まで再生。お礼を言い、おじぎをする。

> 聞いてくださって、ありがとうございました。

## 大人向け・練習と当日のメモ

- 最初に一度、動画を止めながら声に出して通します。4分は設計上の目安で、本人の読み上げ時間は未計測です。3分50秒〜4分10秒くらいを練習の目標にします。
- 再生中の説明が早く終わったら、画面を見てもらう間にします。停止中は表の時刻だけで急に再開せず、本人がその段落を読み終えた合図で再開します。
- 4分を少し超えても、依頼の3〜5分の範囲です。時間に合わせて早口にさせるより、句点ではっきり区切ることを優先します。
- 時間が長いときは、最後の「しっぱいしても、作り直すと少しずつよくなることが分かりました。」を省けます。「一回ずつなので、くつのおかげかはまだ分からない」という説明は残します。
- 「うれしかったです」などの感想は、本人が読んで自分の気持ちに合うか確認し、いつもの言い方に変えてかまいません。
- 実物を舞台に持ち込める場合は、2回目の停止中に完成したくつを少し持ち上げると伝わります。実物なしでも、この台本だけで話せます。
- 会場で動画の再生と一時停止ができるか、事前に確認します。元動画には英語字幕があるため、音声をミュートにし、説明は本人の日本語で伝えます。
- 停止位置は実際の静止画で確認済みです。プレーヤーの操作によるずれがある場合は、秒数と操作表の画面の両方を目印にします。

## 内容の確認に使った資料

- [提出した研究レポート](../report/3d-printed-running-shoes-science-contest.pdf)
- [研究写真と説明](../../images/report/README.md)
- [研究の概要](../../README.md)
- 元動画 `/Users/hide/Downloads/3d-printed-shoes/0909 (1)(1).mp4`
- 表彰式の案内 `/Users/hide/Downloads/IMG_9584.JPG`

400mのタイムは通常のくつが1分56秒、K-Dashが1分51秒で、差は5秒です。各1回の比較なので、くつだけの効果とは言い切らない台本にしています。「軽くした」は初期試作品411gから改良版268gへの比較を指し、通常のくつ204gより軽いという意味ではありません。自作の板はポリカーボネートで、カーボン製とは説明していません。

元動画と研究資料は変更していません。

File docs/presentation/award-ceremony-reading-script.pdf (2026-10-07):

ケーダッシュ の はっぴょう | 1 / 6

01 はじめの あいさつ

はっぴょう 0:00 - 0:20

どうがを ながす

じょうとう小学校

しょうがっこう
3年

さんねん
の、
たけいかなたです。
ぼくは、家

いえ
のスリーディープリンターで、
走

はし
るためのくつを作

つく
りました。
名前

なまえ
は「ケーダッシュ」です。

02 きっかけ

はっぴょう 0:20 - 0:40

とめて はなす

どうが 0:20

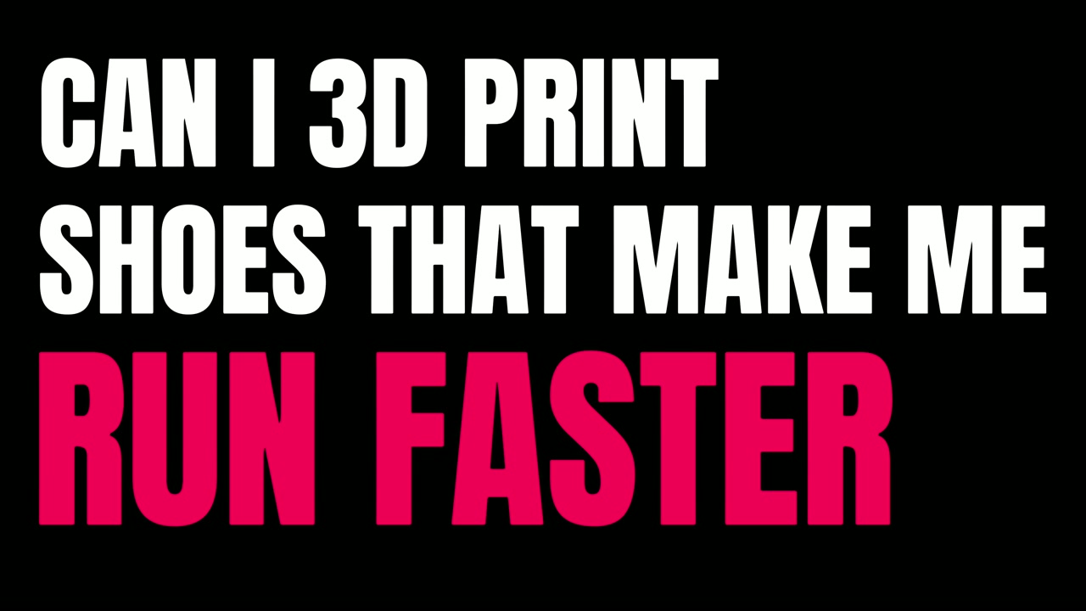
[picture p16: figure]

ぼくは、ランニングクラブで
もっと速

はや
く走

はし
って、
友

とも
だちに勝

か
ちたいと思

おも
っていました。
自分

じぶん
の足

あし
に合

あ
うくつを作

つく
ったら、
もっと速

はや
く走

はし
れるかな、と 考

かんが
えました。

つぎのページへ

03 くつを しらべる

はっぴょう 0:40 - 1:03

どうがを ながす

まず、コーチに 話

はなし
を聞

き
いて、
お店

みせ
のくつを調

しら
べました。
つま先

さき
が上

うえ
を向

む
いた 形

かたち
、あついくつぞこ、
それから、バネのようにしなる板

いた
。
この 3

みっ
つを、ぼくのくつにも取

と
り入

い
れました。

04 あしに あう かたち

はっぴょう 1:03 - 1:25

そのまま ながす

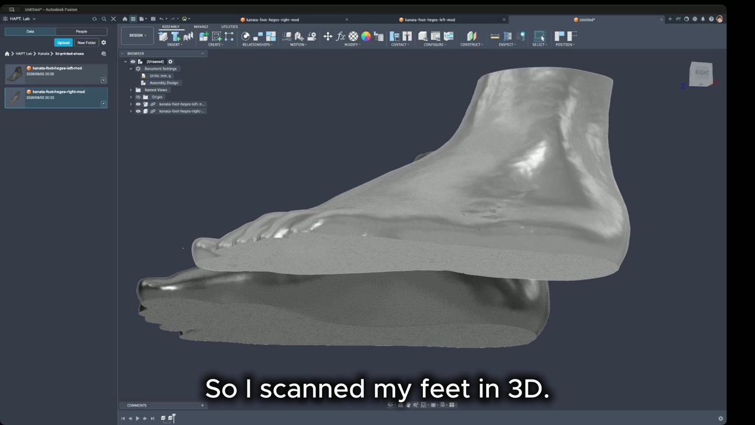
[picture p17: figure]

次

つぎ
に、スマホで自分

じぶん
の足

あし
をうつして、
足

あし
の 形

かたち
をデータにしました。
お父

とう
さんにやり方

かた
を教

おし
えてもらい、
作

つく
りたいくつの 形

かたち
をエーアイに話

はな
して、
形

かたち
を作

つく
りました。

05 はいて たしかめる

はっぴょう 1:25 - 1:40

そのまま ながす
まず、くつの上

うえ
の部分

ぶぶん
を作

つく
って、
はいてみました。
足

あし
にぴったりでした。
でも、くつを全部

ぜんぶ
作

つく
るのは大

たい
へんでした。

06 かるくする くふう

はっぴょう 1:40 - 1:50

そのまま ながす
ざいりょうをかえることで、
さいしょに作

つく
ったくつより、
軽

かる
くすることもできました。

07 いたを いれる

はっぴょう 1:50 - 2:03

そのまま ながす
くつぞこには、曲

ま
げるともどる板

いた
を
入

い
れました。
この板

いた
もプリンターで作

つく
りました。
上下

じょうげ
をくっつけて、できあがりです。

08 できあがり！

はっぴょう 2:03 - 2:43

とめて はなす

どうが 1:43

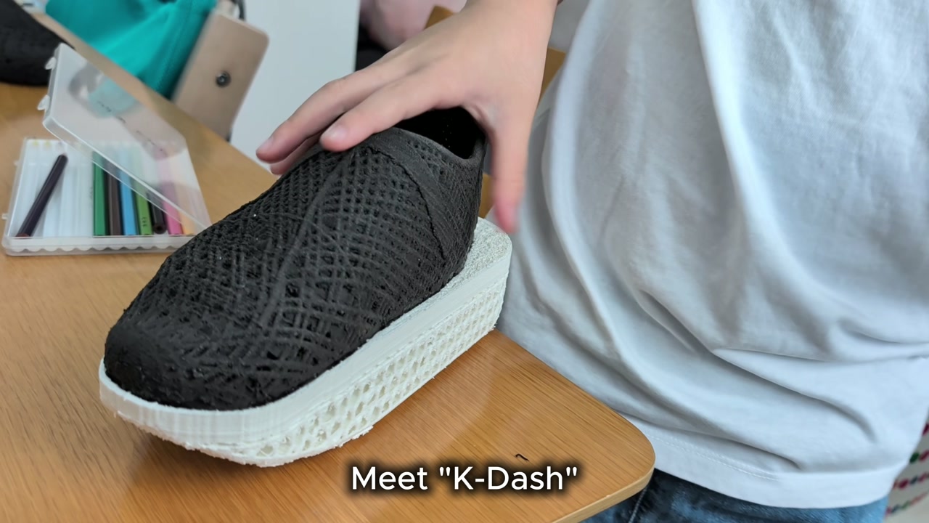
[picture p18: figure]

いちばんむずかしかったのは、
やわらかいざいりょうで作

つく
ることです。
うまく 形

かたち
にならず、何度

なんど
もやり直

なお
しました。
ざいりょうや、プリンターの温度

おんど
を
かえてためしました。
できたものをたしかめて、
うまくいかないところは、
また作

つく
り直

なお
しました。
できたくつで、本当

ほんとう
に速

はや
く走

はし
れるのか、
ためしてみました。

09 はしって くらべる

はっぴょう 2:43 - 2:55

どうがを ながす

できたくつをはいて、
四百

よんひゃく
メートルを走

はし
りました。
ふつうのくつと、ケーダッシュで、
時間

じかん
をくらべました。

10 はしった けっか

はっぴょう 2:55 - 3:10

とめて はなす

どうが 1:55

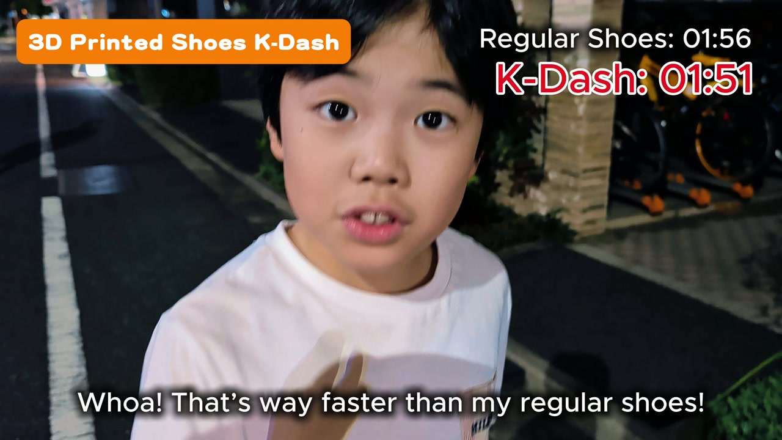
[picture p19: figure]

ふつうのくつでは、一分

いっぷん
五十六

ごじゅうろく
びょう。
ケーダッシュでは、

一分

いっぷん
五十一

ごじゅういち
びょうでした。
今回

こんかい
は、五

ご
びょう速

はや
く走

はし
れました。

11 わかったこと・かんそう

はっぴょう 3:10 - 3:55

とめたまま はなす

どうが 1:55
足

あし
にぴったりで、
前

まえ
に進

すす
みやすい感

かん
じがしました。
でも、くらべたのは、一回

いっかい
ずつです。
くつのおかげで速

はや
くなったかは、
まだ分

わ
かりません。
次

つぎ
は、同

おな
じ場所

ばしょ
で何回

なんかい
か走

はし
って、
たしかめたいです。

自分

じぶん
で 考

かんが
えたくつをはいて走

はし
れて、
うれしかったです。
しっぱいしても、作

つく
り直

なお
すと
少

すこ
しずつよくなることが分

わ
かりました。
もっと軽

かる
くて、
走

はし
りやすいくつを作

つく
りたいです。

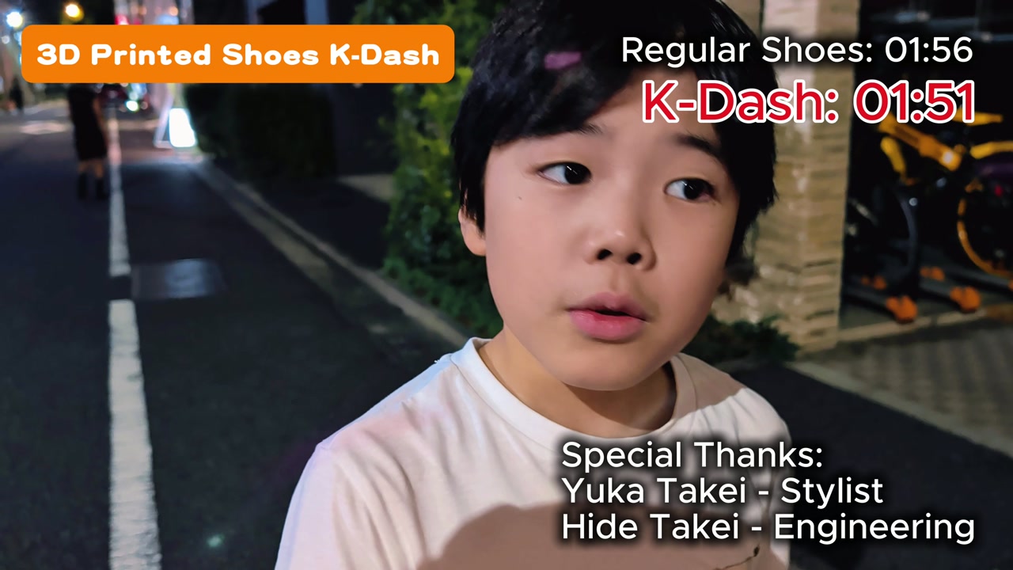
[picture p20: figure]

12 おわり / 3:55 - 4:00
聞

き
いてくださって、
ありがとうございました。

おしまい

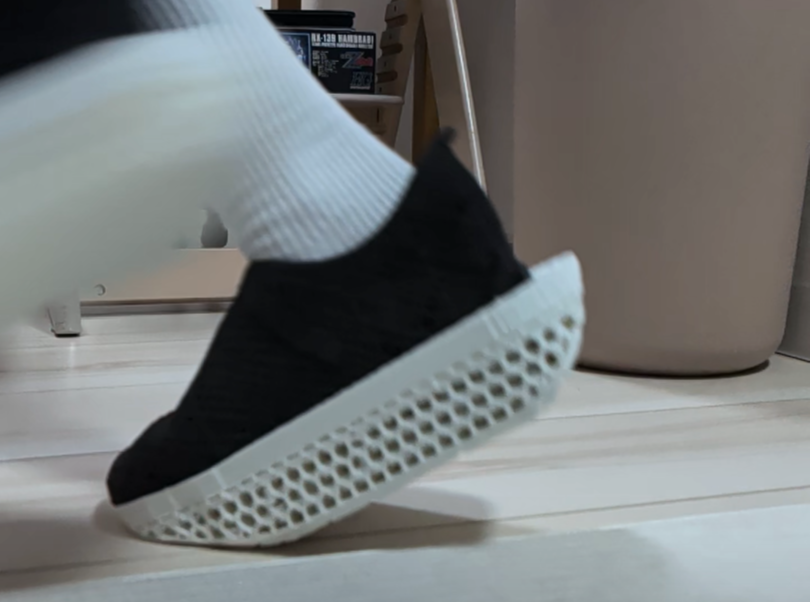
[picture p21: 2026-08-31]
images/report/running-side-view3.png

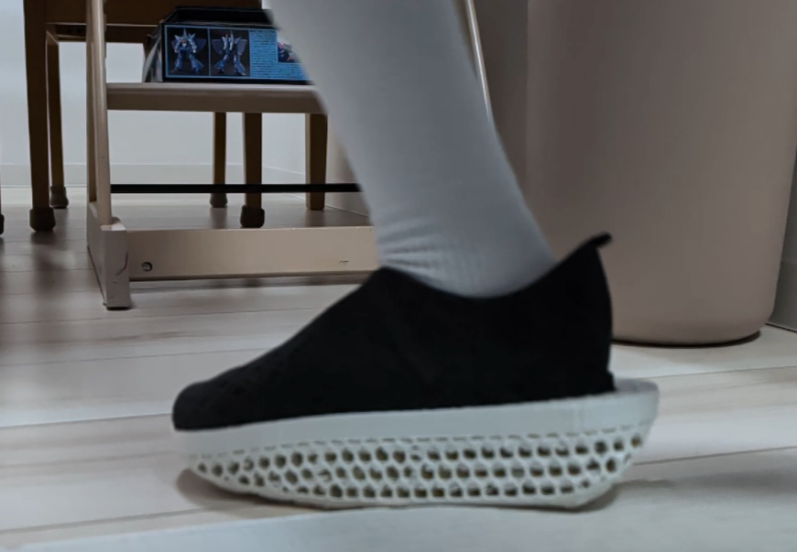
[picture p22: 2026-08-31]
images/report/running-side-view2.png

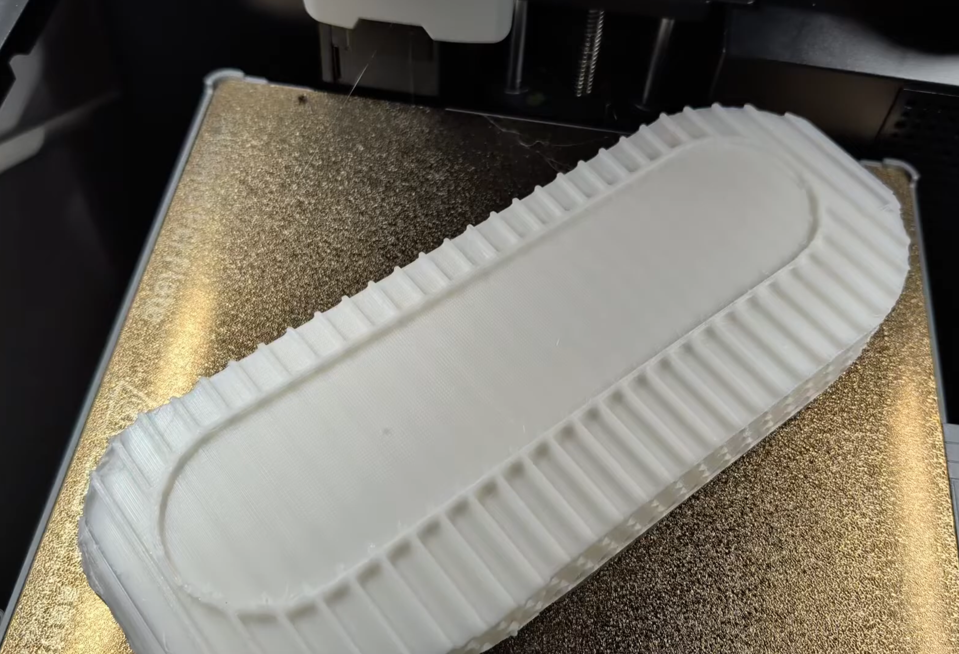
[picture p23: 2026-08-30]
images/report/pc-plate-placement1.png

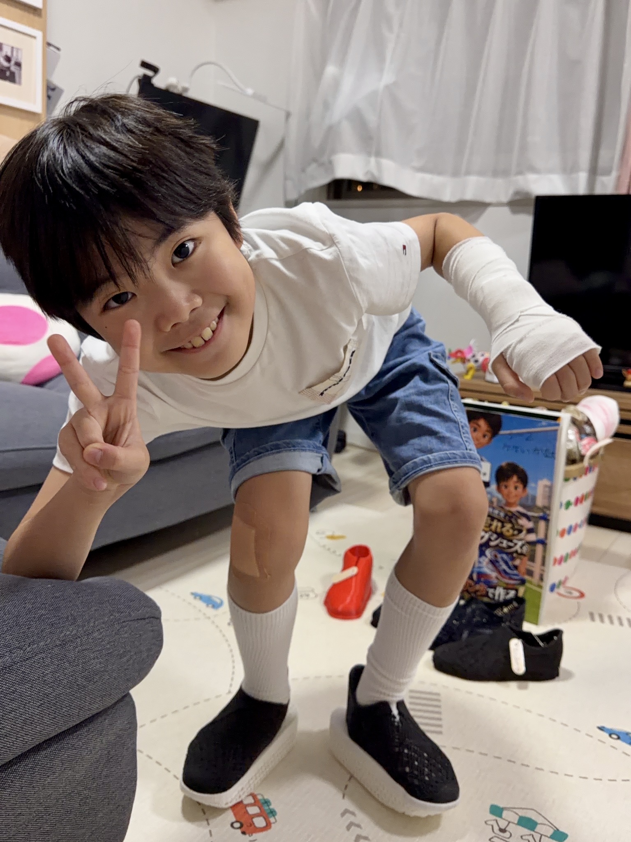
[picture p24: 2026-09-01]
images/report/k-dash-wearing.jpg

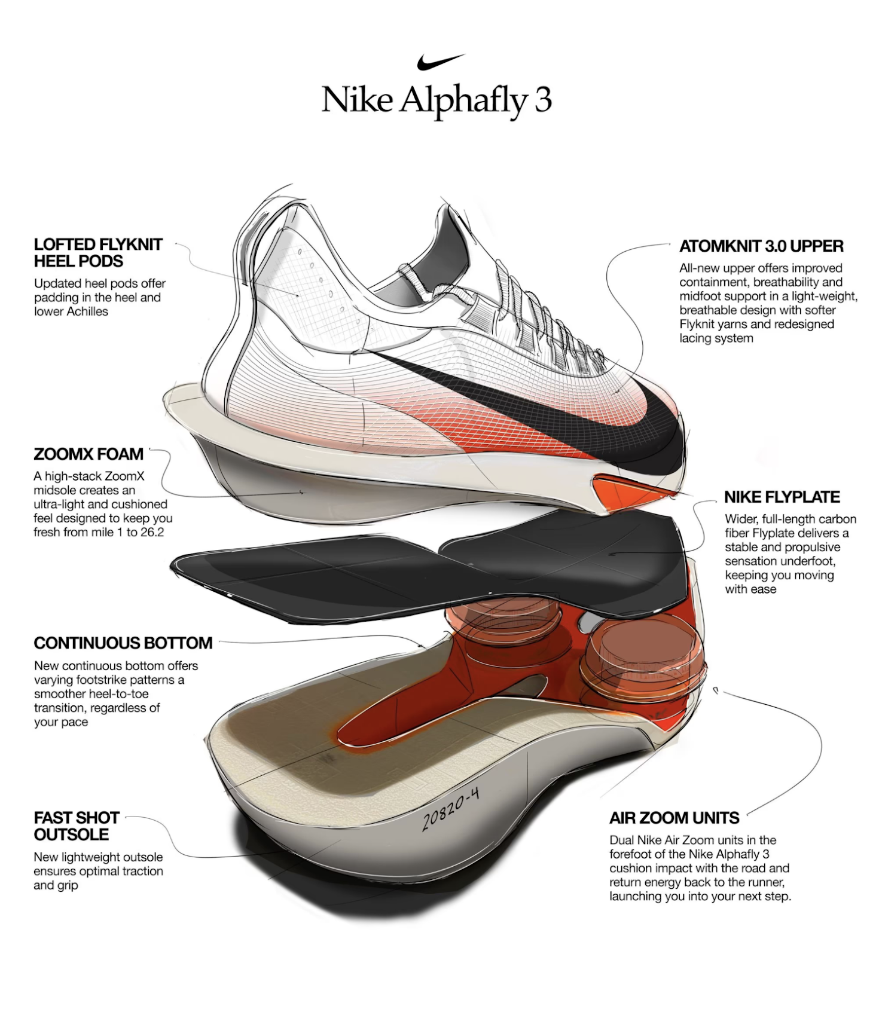
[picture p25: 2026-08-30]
images/report/competitor-nike.png

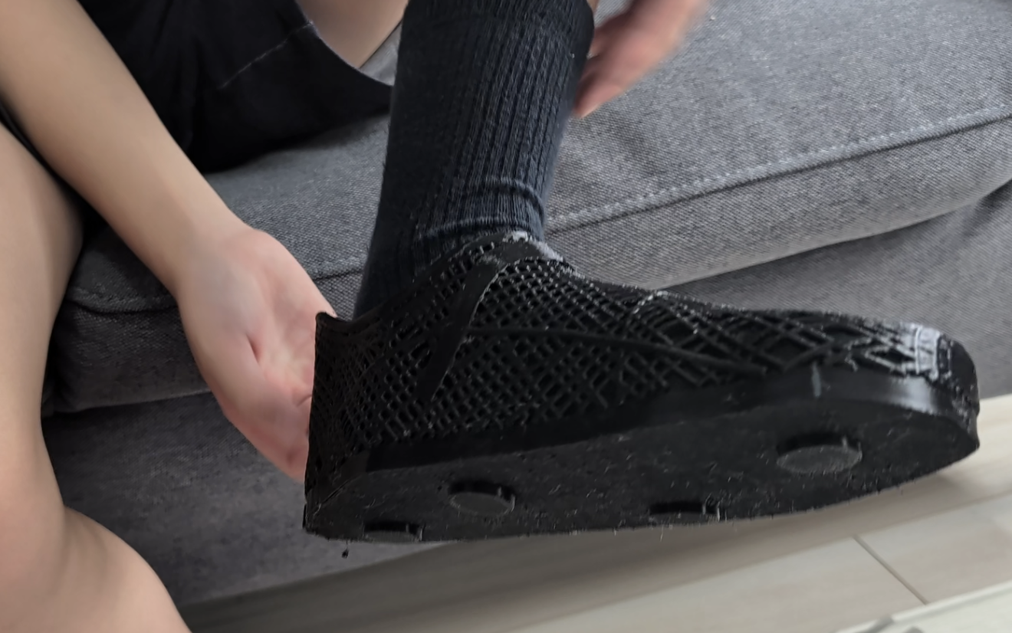
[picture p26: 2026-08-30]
images/report/shoe-upper-finish.png

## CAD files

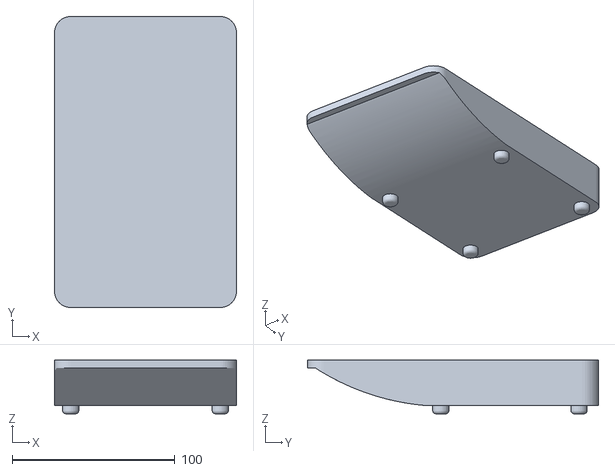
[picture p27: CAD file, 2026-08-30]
3d-models/plate-mold/plate-mold-top.stl
112.0 x 179.0 x 33.0

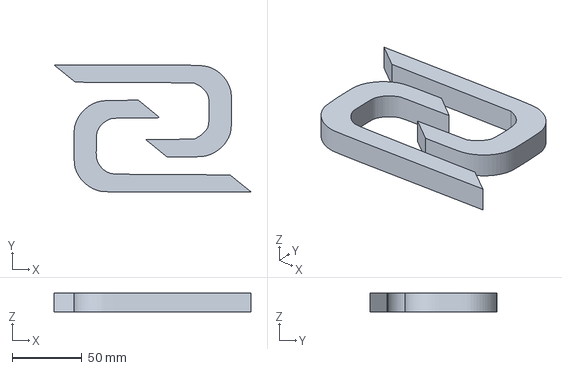
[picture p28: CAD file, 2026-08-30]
3d-models/profiles/nozzle-0.4mm/Siraya Tech TPU AIR 270°C 65A AD 5X 0.4 for Orcaslicer 20260115.3mf
141.1 x 91.1 x 13.4 mm

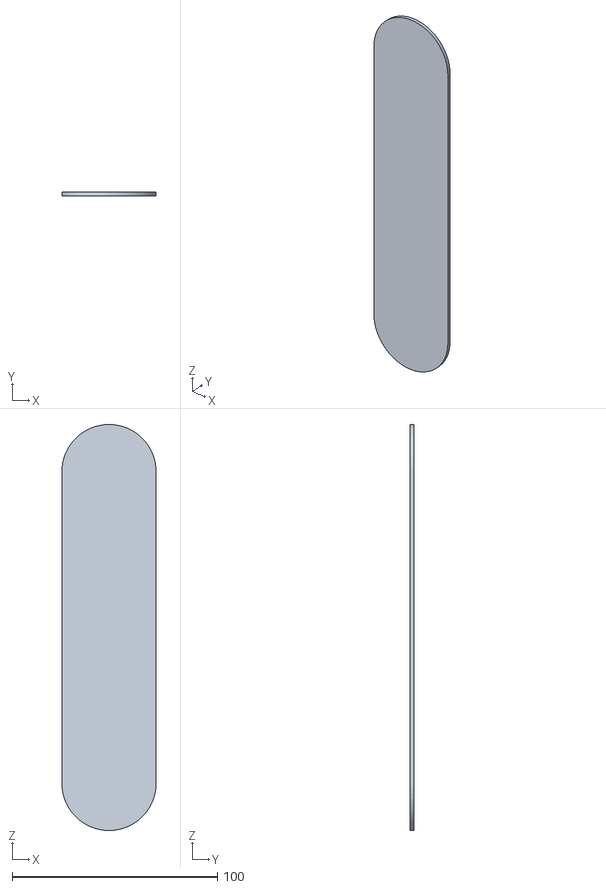
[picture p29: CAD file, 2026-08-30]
3d-models/shoe-plate/shoe-plate2.stl
46.0 x 1.80 x 198.0

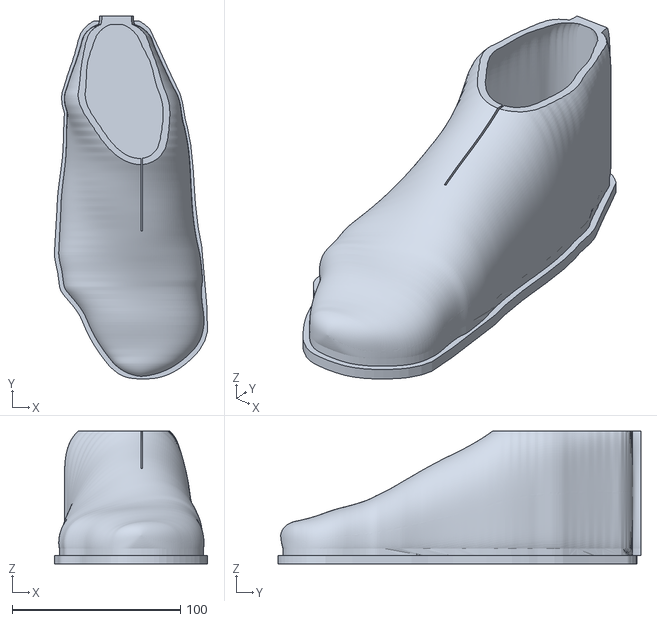
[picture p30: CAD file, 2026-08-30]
3d-models/sole/prototype1/shoe-test.stl
91.1 x 216.1 x 79.0

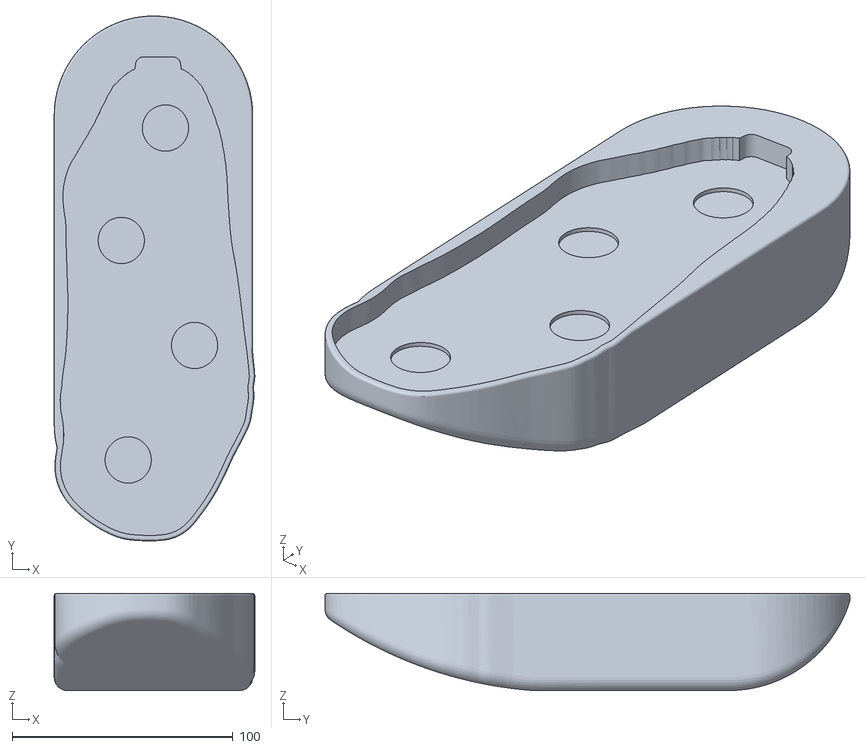
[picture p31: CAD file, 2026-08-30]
sole-ai/data/raw/left/sole-honeycomb-base-left.stl
90.9 x 238.0 x 44.0

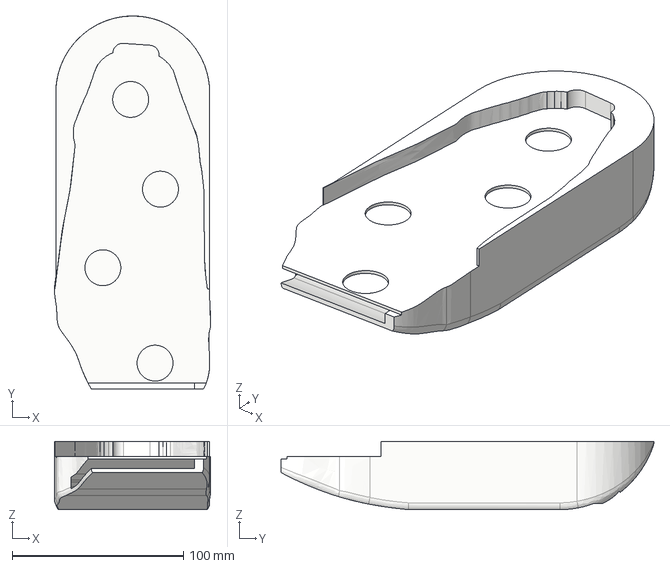
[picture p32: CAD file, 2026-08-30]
sole-ai/data/raw/right/sole-lattice-right.step
91.3 x 218.1 x 40.0 mm

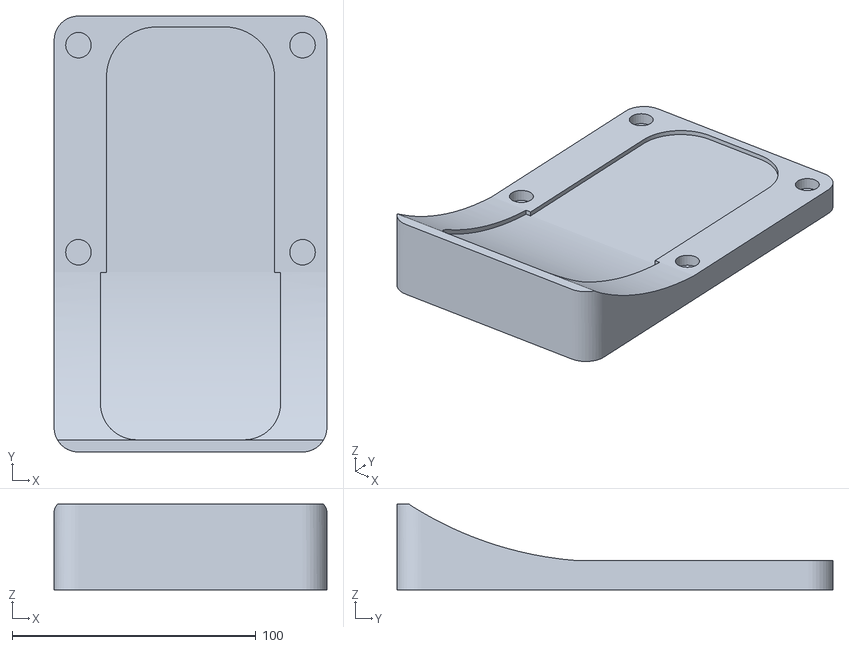
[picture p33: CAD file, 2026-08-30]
3d-models/plate-mold/plate-mold-bottom.stl
112.0 x 179.0 x 35.2

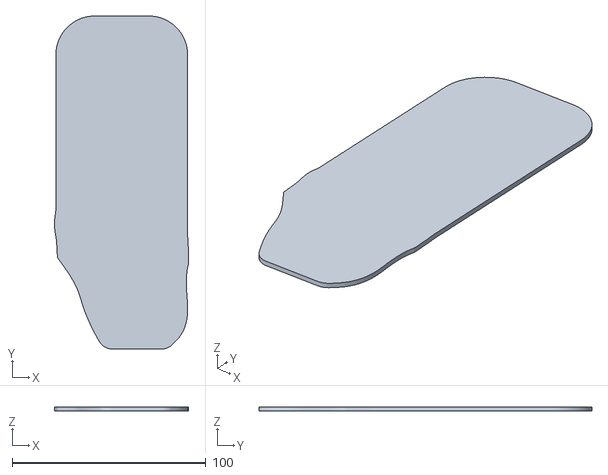
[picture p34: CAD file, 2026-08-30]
3d-models/shoe-plate/shoe-plate-right.stl
69.3 x 171.7 x 2.00

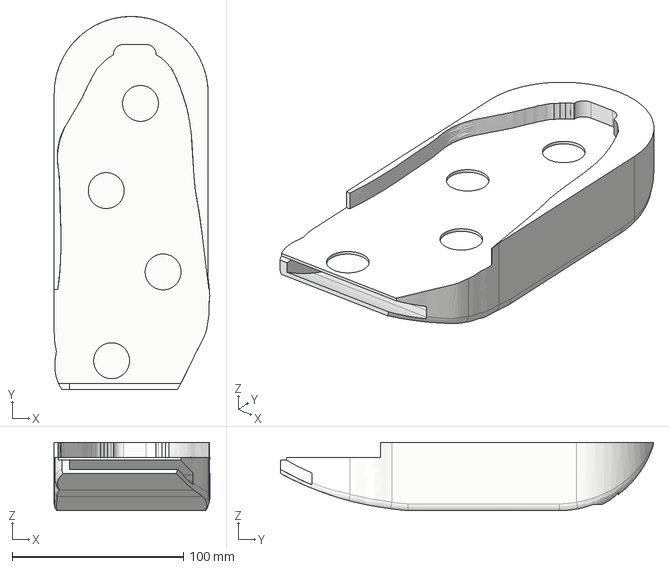
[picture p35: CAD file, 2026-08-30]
sole-ai/data/raw/left/sole-lattice-left.step
90.9 x 218.1 x 40.0 mm

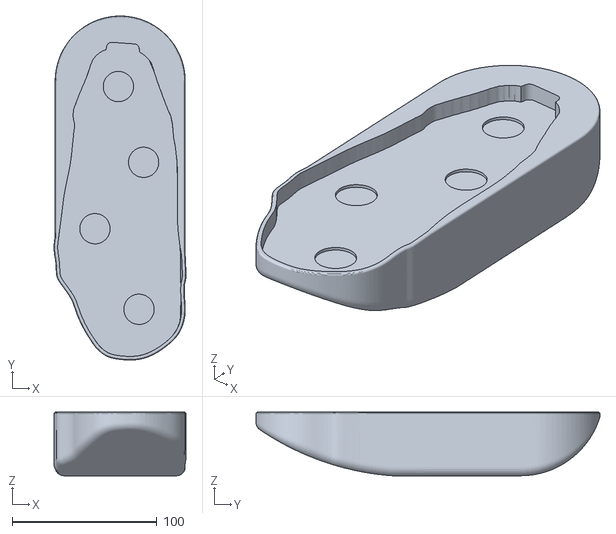
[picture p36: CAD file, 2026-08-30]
sole-ai/data/raw/right/sole-honeycomb-base-right.stl
91.3 x 238.0 x 44.0

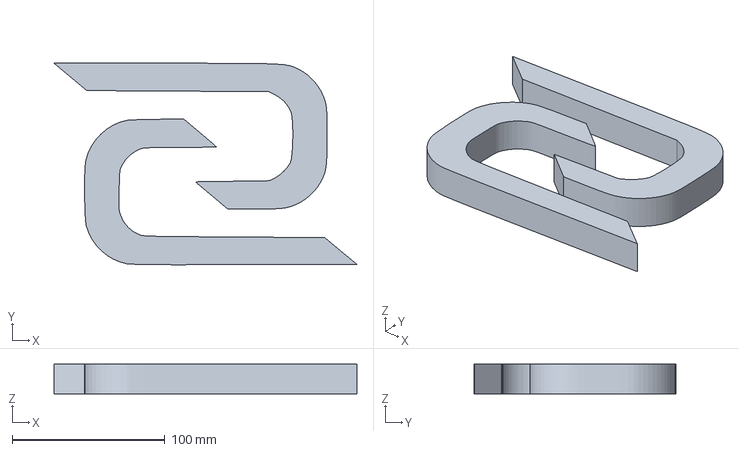
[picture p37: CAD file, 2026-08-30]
3d-models/profiles/nozzle-0.4mm/Siraya Tech TPU 95A AD 5X 0.4 for Orcaslicer 20260112.3mf
198.1 x 131.8 x 19.5 mm

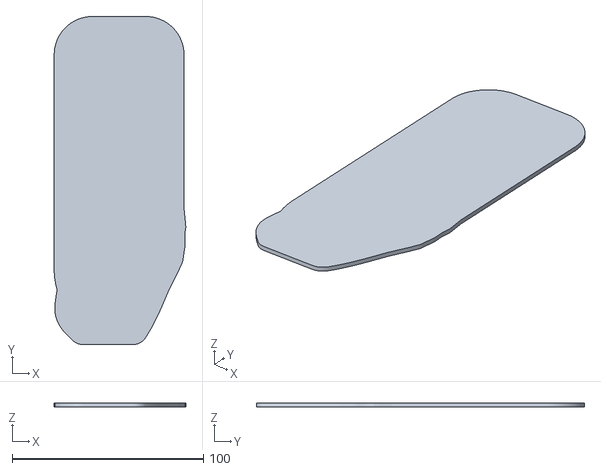
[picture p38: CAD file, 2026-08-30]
3d-models/shoe-plate/shoe-plate-left.stl
68.9 x 171.7 x 2.00

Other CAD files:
3d-models/profiles/nozzle-0.4mm/Siraya Tech TPU 85A AD 5X 0.4 for Orcaslicer 20260115.3mf
3d-models/profiles/nozzle-0.4mm/Siraya Tech TPU AIR 260°C 70A AD 5X 0.4 for Orcaslicer 20260115.3mf
sole-ai/data/raw/left/sole-lattice-left.stl
sole-ai/data/raw/right/sole-lattice-right.stl

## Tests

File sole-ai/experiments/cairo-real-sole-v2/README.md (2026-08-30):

# Cairo Bio-Cell Side-Reveal — actual sole candidate

This generator uses the supplied `sole-lattice-left.stl` and
`sole-lattice-right.stl` directly. It does not scale a cube, mirror one foot, or
replace the scanned outline with a generic shoe shape.

The solid is a row of side-facing pentagonal arches clipped independently to
every vertical solid interval in the source STL. V2 adds continuous 1.5 mm upper
and lower load-spreading skins; the lateral faces remain open so the printed
cellular construction is visible.

V2 raises the walls to the project's 1.5 mm minimum and reduces the pitch from
V1's 22 mm to about 7.3 mm.
That produces roughly thirty transverse arches across a 218 mm sole, tripling
the support frequency without thickening each wall. Two internal longitudinal
rails tie the arch legs together and resist progressive lateral buckling. The
proof-load target is 1.24 kN: 28 kg, three bodyweights, and a 1.5 safety factor.
The anti-buckling rails terminate into transverse arch legs rather than being
clipped by the external toe, heel, top, or bottom surfaces.
The scalar grid uses a non-rational phase offset so source faces do not coincide
with marching-grid vertices and create point-contact non-manifold edges.
Field samples within 0.005 mm of the isosurface are moved away from zero without
changing material/void classification. This prevents sub-resolution triangles
at grid nodes and is one third of one percent of the 1.5 mm structural wall.
Numerical marching slivers are removed at the project's 0.00001 mm mesh-QA
tolerance, five orders of magnitude below the 1.5 mm structural wall.
This target must be verified on the selected printed TPE before running. The output is geometry-checked for a closed
two-manifold STL, but running use still requires print, compression, peel, and
fatigue tests.

The selected material is eSUN eLastic TPE-83A, not the earlier TPU-95A
assumption. eSUN reports 1.14 g/cm3 density, 29 MPa XY tensile strength, 7.53
MPa Z tensile strength, over 400% XY elongation, and 129.7% Z elongation. The
large directional difference makes layer adhesion a required test item. The
official baseline is 220--250 C nozzle, 45--60 C bed, 100% fan, below 50 mm/s,
and drying at 55 C for more than four hours. These are starting settings, not a
substitute for AD5X coupons and a full-sole proof/fatigue test.

Official material page:
https://www.esun3d.com/elastic-tpe-83a-product/

The left-foot physical acceptance sequence is documented in
`LEFT_TPE83A_TEST_PLAN.md`.

Run the fast unit gates with:

```sh
python3 -m unittest discover -s tests
```

Generate a coarse visual-review STL with `--preview`; omit it for the 0.70 mm
production mesh.

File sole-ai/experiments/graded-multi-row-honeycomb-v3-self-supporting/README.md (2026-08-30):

# Self-Supporting Graded Honeycomb V3.1 — independent left/right soles

This generator uses the supplied `sole-lattice-left.stl` directly. It does not
mirror the opposite foot, scale a cube, or replace the scanned outline with a
generic shoe shape. Left and right inputs are processed independently rather
than mirrored. Earlier designs remain available separately and are not
overwritten.

## Architecture

V3.1 uses a
point-top hexagonal network spans the complete sole height. Each cell is 8 mm
wide and 13 mm tall, with 4 mm vertical sides and four 6.02 mm diagonal sides.
The diagonals rise 48.37 degrees from the build plate. Therefore the internal
honeycomb contains zero build-plate-parallel edges: every cell segment is
vertical or rises above 45 degrees. Every internal node still joins three short
walls. The supplied 40 mm left volume is covered by 28 columns, four rows, and
171 cells; the side openings expose the printed structure.

The continuous upper skin remains a horizontal surface by design, so the
finished sole is not literally bridge-free. Pointed cell crowns support that
skin at short intervals. The actual AD5X/TPE profile still needs a print coupon
to confirm that those local spans close without sagging.

Wall thickness provides the smooth density grade without breaking cell
continuity:

- central arch: 1.5 mm;
- heel and forefoot: 1.8 mm;
- transitions use a smooth cubic curve rather than a hard boundary.

Continuous 1.5 mm upper and lower skins spread landing load. Two 1.5 mm
internal longitudinal rails rise continuously from the lower skin to the upper
skin. The proof-load design target remains 1.24 kN: 28 kg, three bodyweights,
and a 1.5 safety factor.

A 0.2 mm lateral raster guard keeps the generated mesh inside the supplied STL
envelope instead of allowing coarse-grid interpolation to protrude beyond it.

## Material and qualification boundary

The selected material is eSUN eLastic TPE-83A. eSUN reports 1.14 g/cm3 density,
29 MPa XY tensile strength, 7.53 MPa Z tensile strength, over 400% XY
elongation, and 129.7% Z elongation. The official baseline is 220--250 C nozzle,
45--60 C bed, 100% fan, below 50 mm/s, and drying at 55 C for more than four
hours.

Official material page:
https://www.esun3d.com/elastic-tpe-83a-product/

The geometry is checked for a closed two-manifold STL, one connected material
body, zero horizontal internal honeycomb edges, and a minimum 45 degree rising
wall angle. Those checks do not prove running safety. The intended AD5X
profile must pass coupons, a 1,236 N static proof, and the cyclic sequence in
`LEFT_TPE83A_TEST_PLAN.md` before human running.

## Reproducibility

Run the fast geometry gates with:

```sh
python3 -m unittest discover -s tests
```

Generate a visual-review STL with `--preview`; omit it for the 0.70 mm
production mesh. Print flat with Z as the layer-stack direction.

## 30 mm printability box

`cairo_real_sole.coupon` creates a rail-free V3.2 sample after the first physical
coupon showed excessive stiffness from the two longitudinal rails. The rail-
free sample retains the V3.1 honeycomb and upper/lower skins in a nominal
30 x 30 x 30 mm cube. Its production grid is
0.50 mm so the 1.5 mm minimum wall is represented by at least three samples.
Place the lower 30 x 30 mm face on the build plate. The coupon checks support-
free geometry and comparative stiffness only; it is not a running-load proof.

## New base-STL full sole with plate pocket

`cairo_real_sole.honeycomb_base` processes
`sole-honeycomb-base-left.stl` and `sole-honeycomb-base-right.stl`
independently. It does not mirror either foot. This V3.2 variant removes the
two internal longitudinal rails after the 30 mm physical sample showed that
they made the structure too stiff.

The region above the nested 2.2 mm cutter remains the original solid upper.
The lower honeycomb retains a continuous 1.5 mm pocket-floor skin and a
continuous 1.5 mm ground-facing skin. A 1.5 mm solid perimeter encloses the
plate pocket for a pause-and-insert print. No solid lateral skins are added to
the lower section, so its honeycomb cross-section remains visible on both
sides. The supplied STL remains the clipping envelope and controls the actual
outline and vertical profile. Generate the left preview with:

```sh
python3 -m cairo_real_sole.honeycomb_base \
  sole-honeycomb-base-left.stl sole-honeycomb-left-preview.stl \
  --sole-ai-root /path/to/sole-ai --side left --preview
```

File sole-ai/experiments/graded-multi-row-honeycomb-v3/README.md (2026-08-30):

# Graded Multi-Row Honeycomb V3 — left sole

This generator uses the supplied `sole-lattice-left.stl` directly. It does not
mirror the opposite foot, scale a cube, or replace the scanned outline with a
generic shoe shape. V2 remains available separately and is not overwritten.

## Architecture

V3 replaces V2's long lower vertical legs and top-only triangular braces with a
flat-top hexagonal network spanning the complete sole height. On the 40 mm left
designer volume the network contains four staggered rows, 26 longitudinal
columns, and 154 cells. Every internal node joins three short walls, and no
unbraced segment is longer than the 5.5 mm cell edge.

The 5.5 mm edge produces 9.5 mm-tall cells. Steep diagonal walls are friendly
to flat-bed FFF printing; each short horizontal bridge is supported at both
ends. Side openings intentionally expose the printed honeycomb.

Wall thickness provides the smooth density grade without breaking cell
continuity:

- central arch: 1.5 mm;
- heel and forefoot: 1.8 mm;
- transitions use a smooth cubic curve rather than a hard boundary.

Continuous 1.5 mm upper and lower skins spread landing load. Two 1.5 mm
internal longitudinal rails link the transverse honeycomb plates and resist
out-of-plane buckling. The proof-load design target remains 1.24 kN: 28 kg,
three bodyweights, and a 1.5 safety factor.

A 0.2 mm lateral raster guard keeps the generated mesh inside the supplied STL
envelope instead of allowing coarse-grid interpolation to protrude beyond it.

## Material and qualification boundary

The selected material is eSUN eLastic TPE-83A. eSUN reports 1.14 g/cm3 density,
29 MPa XY tensile strength, 7.53 MPa Z tensile strength, over 400% XY
elongation, and 129.7% Z elongation. The official baseline is 220--250 C nozzle,
45--60 C bed, 100% fan, below 50 mm/s, and drying at 55 C for more than four
hours.

Official material page:
https://www.esun3d.com/elastic-tpe-83a-product/

The geometry is checked for a closed two-manifold STL and a single connected
material body. Those checks do not prove running safety. The intended AD5X
profile must pass coupons, a 1,236 N static proof, and the cyclic sequence in
`LEFT_TPE83A_TEST_PLAN.md` before human running.

## Reproducibility

Run the fast geometry gates with:

```sh
python3 -m unittest discover -s tests
```

Generate a visual-review STL with `--preview`; omit it for the 0.70 mm
production mesh.

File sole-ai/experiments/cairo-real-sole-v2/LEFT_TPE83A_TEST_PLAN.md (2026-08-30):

# Left sole TPE-83A running gate

This document defines the minimum physical gate for the left-foot V2 candidate.
It does not certify the shoe. Do not perform a human running test until every
gate below passes on a part printed with the intended AD5X profile.

## Fixed design basis

- Runner mass: 28 kg.
- Conservative running peak: 3.0 bodyweights = 824 N on one foot.
- Structural proof target: 824 N x 1.5 = 1,236 N.
- Material: eSUN eLastic TPE-83A, dried at 55 C for more than four hours.
- Geometry: 1.5 mm minimum walls, 30 transverse cells, two longitudinal rails,
  and continuous 1.5 mm upper/lower load-spreading skins.

## 1. Print-process coupons

Print coupons beside the sole with the same dried spool, nozzle, temperatures,
speed, layer height, cooling, and build orientation. Reject the build for
under-extrusion, wet-filament bubbles, gaps at junctions, or visible layer
separation. The Z-direction coupon is mandatory because eSUN reports much lower
Z tensile strength than XY strength for this material.

## 2. Static proof compression

1. Measure initial height at heel, midfoot, and forefoot.
2. Compress the complete sole between representative upper and outsole plates.
3. Ramp from 0 N to 824 N over at least 10 seconds; record displacement.
4. Continue to 1,236 N and hold for 60 seconds.
5. Unload, wait 30 minutes, then repeat the three height measurements.

Pass only if there is no crack, layer split, skin separation, sudden load drop,
or cell-wall inversion. At 824 N, displacement must not exceed 30% of the local
sole height. After recovery, permanent height loss must be at most 5% locally.

## 3. Running-cycle compression

Cycle the assembled sole from 50 N to 824 N for 10,000 cycles at no more than
3 Hz. Stop every 1,000 cycles to inspect the toe, forefoot, heel, cell junctions,
and both load-spreading skins. Record peak displacement and surface temperature.

Pass only if peak displacement grows by at most 10% from the first 100 cycles,
there is no progressive heating trend, no crack or delamination, and the same
5% permanent-set limit is met 30 minutes after the final cycle.

## 4. Human-use sequence

After all bench gates pass, begin with standing, walking, short straight-line
jogs, and only then a supervised 1 km run. Reinspect after each stage. Any new
noise, asymmetric collapse, bottoming, tear, or permanent lean is a failure.

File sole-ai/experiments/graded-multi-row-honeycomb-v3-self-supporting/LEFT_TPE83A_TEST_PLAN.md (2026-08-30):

# Left sole TPE-83A running gate

This document defines the minimum physical gate for the left-foot V3.1 candidate.
It does not certify the shoe. Do not perform a human running test until every
gate below passes on a part printed with the intended AD5X profile.

## Fixed design basis

- Runner mass: 28 kg.
- Conservative running peak: 3.0 bodyweights = 824 N on one foot.
- Structural proof target: 824 N x 1.5 = 1,236 N.
- Material: eSUN eLastic TPE-83A, dried at 55 C for more than four hours.
- Geometry: point-top honeycomb with no horizontal internal cell edges, at
  least 48.37-degree diagonals, 1.5--1.8 mm graded walls, two longitudinal
  bottom-to-top vertical rails, and continuous 1.5 mm upper/lower
  load-spreading skins.

## 1. Print-process coupons

Print coupons beside the sole with the same dried spool, nozzle, temperatures,
speed, layer height, cooling, and build orientation. Reject the build for
under-extrusion, wet-filament bubbles, gaps at junctions, or visible layer
separation. Include the upper-skin span over at least four cell crowns so sag is
measured in the intended flat orientation. The Z-direction coupon is mandatory
because eSUN reports much lower Z tensile strength than XY strength for this
material.

## 2. Static proof compression

1. Measure initial height at heel, midfoot, and forefoot.
2. Compress the complete sole between representative upper and outsole plates.
3. Ramp from 0 N to 824 N over at least 10 seconds; record displacement.
4. Continue to 1,236 N and hold for 60 seconds.
5. Unload, wait 30 minutes, then repeat the three height measurements.

Pass only if there is no crack, layer split, skin separation, sudden load drop,
or cell-wall inversion. At 824 N, displacement must not exceed 30% of the local
sole height. After recovery, permanent height loss must be at most 5% locally.

## 3. Running-cycle compression

Cycle the assembled sole from 50 N to 824 N for 10,000 cycles at no more than
3 Hz. Stop every 1,000 cycles to inspect the toe, forefoot, heel, cell junctions,
and both load-spreading skins. Record peak displacement and surface temperature.

Pass only if peak displacement grows by at most 10% from the first 100 cycles,
there is no progressive heating trend, no crack or delamination, and the same
5% permanent-set limit is met 30 minutes after the final cycle.

## 4. Human-use sequence

After all bench gates pass, begin with standing, walking, short straight-line
jogs, and only then a supervised 1 km run. Reinspect after each stage. Any new
noise, asymmetric collapse, bottoming, tear, or permanent lean is a failure.

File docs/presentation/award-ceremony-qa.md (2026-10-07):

<!-- docs/presentation/award-ceremony-qa.md | 表彰式の質問回答集 | 小学3年生が研究について自分のことばで答える練習をするため。 -->

# けんきゅうのしつもんと、答えのれんしゅう

[4分の発表台本](award-ceremony-4min-script.md)といっしょに使います。

## れんしゅうのしかた

まずは、1〜10のしつもんをれんしゅうしましょう。答えを全部おぼえなくても、だいじなことが言えれば大じょうぶです。下の答えは「言い方のれい」なので、自分が話しやすいことばにかえてかまいません。

答えは、ふつうの速さで二、三文くらい。もっと聞かれたら、くわしく話しましょう。分からないときに使えることばも、さいごにあります。

## まず、れんしゅうする10問

### 1．なぜ、このけんきゅうをしようと思ったのですか？

> ランニングクラブで、もっと速く走って、友だちに勝ちたいと思ったからです。
> 自分の足に合うくつを作ったら、もっと速く走れるかな、と考えました。

### 2．どんなことを調べたのですか？

> 自分の足に合う、走るためのくつを、家のスリーディープリンターで作りました。
> できたくつをはいて、ふつうのくつと走る時間をくらべました。

### 3．このくつの、くふうしたところはどこですか？

> 自分の足の形をデータにして、それに合うくつを作ったところです。
> つま先を上に向けたり、くつぞこの中に板を入れたりしました。

### 4．いちばん大へんだったことは何ですか？

> やわらかいざいりょうを、思った形にすることです。
> プリンターでうまく作れなくて、何度もやり直しました。

### 5．うまくいかないときは、どうしましたか？

> ざいりょうや、プリンターの温度をかえてためしました。
> できたものを見て、うまくいかないところは、また作り直しました。

### 6．走る時間は、どうなりましたか？

> 四百メートルで、ふつうのくつは一分五十六びょうでした。
> ケーダッシュは一分五十一びょうで、今回は五びょう速く走れました。

### 7．くつのおかげで速くなったと、言えますか？

> まだ、はっきりとは言えません。
> くらべたのは一回ずつなので、同じ場所で何回か走って、たしかめたいです。

### 8．お父さんには、何を手つだってもらいましたか？

> 自分の足に合うくつを作りたいと考えたのは、ぼくです。
> お父さんには、足をデータにすることや、形の作り方、ざいりょうやプリンターの使い方を手つだってもらいました。

### 9．エーアイは、何を手つだってくれましたか？

> ぼくが作りたい形を話すと、パソコンの中で形を作るのを手つだってくれました。
> できたくつをはいて、足に合うかは自分でたしかめました。

### 10．これから、どんなことをしたいですか？

> もっと軽くて、走りやすいくつを作りたいです。
> 次は、もう少し長いきょりでも走って、くらべたいです。

## 作り方を、くわしく聞かれたら

### 11．スリーディープリンターは、どんなきかいですか？

> パソコンで作った形を、ざいりょうを少しずつ重ねて作るきかいです。
> ぼくは、このきかいでくつのパーツを作りました。

### 12．足の形は、どうやって調べましたか？

> スマホのアプリで、右足と左足の形をデータにしました。
> まわりのいらないところをけして、足だけの形にしました。

### 13．なぜ、さいしょはくつの上の部分だけを作ったのですか？

> まず、自分の足に合うかをたしかめたかったからです。
> はいてみると、足にぴったりでした。

### 14．コーチからは、どんなことを教わりましたか？

> 走るためのくつには、いろいろなくふうがあると教わりました。
> つま先が上を向いた形、あついくつぞこ、中に入っている板を、ぼくのくつのさんこうにしました。

### 15．くつぞこに、あながたくさんあるのはなぜですか？

> 中を全部うめると重くなるので、すきまのある形にしました。
> はちのすのような形にして、軽くて、クッションになるくつぞこを目ざしました。

### 16．どんなざいりょうを使いましたか？

> 何しゅるいかためして、かたさや、はいた感じをくらべました。
> さいごは、ティーピーユー・エアという、やわらかいざいりょうを使いました。

### 17．くつの中の板は、何のために入れたのですか？

> 曲げるともどる力を、走るときに使えないかなと思って入れました。
> この板だけで、どれくらい速くなるかは、まだ分かりません。

### 18．お店のくつと、同じ板を使ったのですか？

> お店のくつで調べたカーボンの板は、家では作りにくかったです。
> そこで、ポリカーボネートというざいりょうで作りました。
> 曲げると、もとの形にもどろうとしました。

### 19．板を、どうやってくつの中に入れましたか？

> くつぞこを作っているとちゅうで、プリンターを止めて板を入れました。
> そのあと、また作り始めて、板を中に入れこみました。

## 走ったけっかや、これからのことを聞かれたら

### 20．ふつうのくつより、軽くできましたか？

> さいしょに作ったくつよりは、軽くできました。
> でも、くらべたふつうのくつよりは、まだ重いです。
> もっと軽くするくふうをしたいです。

### 21．はいて走ると、どんな感じでしたか？

> 足にぴったりでした。
> つま先が上を向いているので、前に進みやすい感じがしました。

### 22．次は、どうやって走る時間をくらべたいですか？

> 同じ場所で、同じきょりを、何回か走りたいです。
> 先にはくくつのじゅんばんも入れかえて、くらべたいです。

### 23．ずっとはいて走っても、こわれませんか？

> 今回のけんきゅうでは、四百メートルを走ってたしかめました。
> 長く使ったときに、こわれないかも、これから調べたいです。

### 24．ほかの人も、このくつをはけますか？

> これは、ぼくの足に合わせて作ったくつです。
> ほかの人がはくなら、その人の足にも合うか、たしかめたいです。

### 25．このけんきゅうをして、何が分かりましたか？

> 思ったとおりに作るのは、むずかしかったです。
> でも、うまくいかないところを考えて作り直すと、少しずつよくなることが分かりました。

### 26．しょうをもらって、どんな気もちですか？

> とてもうれしいです。
> 何度も作り直したので、がんばってよかったと思いました。
> これからも、作ったり、ためしたりしたいです。

## 分からないときや、こまったとき

### しつもんが、よく聞こえなかったら

> すみません。もう一度、しつもんをおねがいします。

### しつもんの意味が、分からなかったら

> すみません。もう少し、やさしいことばで教えてください。

### まだ、ためしていないことを聞かれたら

> そこは、まだためしていないので分かりません。
> これから、たしかめてみたいです。

### 数字を、正しくおぼえていなかったら

> 今は、正しい数字をおぼえていません。
> たしかめてから、お答えしたいです。

### 少し考えてから答えたいとき

> 少し考えてもいいですか。

## 数字のメモ

数字を聞かれたときだけ、見て答えても大じょうぶです。

| くらべたこと | けっか |
| --- | --- |
| 走ったきょり | 400メートル。よんひゃくメートル |
| ふつうのくつの時間 | 1分56びょう。いっぷん、ごじゅうろくびょう |
| ケーダッシュの時間 | 1分51びょう。いっぷん、ごじゅういちびょう |
| 時間のちがい | 今回は5びょう速かった |
| くらべた回数 | それぞれ1回ずつ |
| ふつうのくつの重さ | 204グラム。にひゃくよんグラム |
| さいしょに作ったくつの重さ | 411グラム。よんひゃくじゅういちグラム |
| 作り直したくつの重さ | 268グラム。にひゃくろくじゅうはちグラム |
| さいしょのくつから軽くなった分 | 143グラム。ひゃくよんじゅうさんグラム |

## 保護者向け・練習前に確認すること

以下は読み上げ用ではありません。回答は提出した研究レポートと発表台本に合わせています。本人の担当や気持ちは、練習で本人に確認し、実際と違う表現があれば直してください。特に8・9の分担、25・26の感想を確認します。

22の「走る順番を入れ替える」は、次の実験方法としての提案です。実施済みの事実ではありません。本人が意味を理解し、やってみたいと思う場合に使ってください。23は提出時の研究の範囲に合わせた答えなので、その後に追加の試験をしていれば更新してください。

資料で確認できない次の内容は、数字や理由を作らず、練習前に記入します。未記入のまま丸暗記する必要はありません。

| 聞かれそうな質問 | 家で確認しておく答え |
| --- | --- |
| 作るのに何日かかりましたか？ | 研究全体で約＿＿日。プリンターが動いた時間とは区別する |
| くつ一つを作るのに何時間かかりますか？ | どの部品・どの版かを確認し、記録から＿＿時間 |
| いくらかかりましたか？ | 材料費で約＿＿円。失敗分や機械代を含むかも確認する |
| 何回くらい失敗しましたか？ | 記録があれば＿＿回。不明なら「何度もやり直しました」まで |
| なぜ「ケーダッシュ」という名前にしたのですか？ | 本人が付けた理由を、そのまま＿＿＿＿ |
| 友だちに勝てましたか？ | 実際の結果を確認する。今回の記録は自分が履くくつの比較 |

「資料に書かれていない」と「本人が知らない」は別です。本人が覚えていることや記録で確認できることは、その内容で答えてください。費用・日数・名前の理由は、この回答集では未確認です。

回答では、次の区別を保っています。

- 今回5秒速かったという結果と、くつの効果が確かだと言えるかは別。各1回の比較だけで効果を断定しません。
- 「軽くできた」は初期試作品411gから改良版268gへの比較。通常のくつ204gよりは重いままです。
- 板の材料はポリカーボネート。市販靴のカーボン板と同じ素材とは説明しません。
- はき心地は本人の感想。板やつま先の形がタイムにどれだけ効いたかを、個別に測定したとは説明しません。
- 15の軽さ・クッションは設計のねらい。穴のない靴底との比較で、効果を証明したという答えにはしません。

## 確認に使った資料

- [4分の発表台本](award-ceremony-4min-script.md)
- [提出した研究レポート](../report/3d-printed-running-shoes-science-contest.pdf)
- [研究の概要](../../README.md)
- [研究写真と説明](../../images/report/README.md)
- [研究の経緯と役割のメモ](../report/2026-08-30%2016_32_11.md)

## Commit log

2026-08-30 feat: add sole AI design pipeline
    [sole-honeycomb-base-left.stl, sole-honeycomb-base-right.stl, sole-lattice-left.step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]
2026-08-30 assets: add selected 3D shoe models
    [Siraya Tech TPU 85A AD 5X 0.4 for Orcaslicer 20260115.3mf, Siraya Tech TPU 95A AD 5X 0.4 for Orcaslicer 20260112.3mf, Siraya Tech TPU AIR 260°C 70A AD 5X 0.4 f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]
